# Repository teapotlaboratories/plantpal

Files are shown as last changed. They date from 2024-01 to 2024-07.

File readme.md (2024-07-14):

# Teapotlabs Plantpal
 
 
Meet Teapotlabs Plantpal -  Your pal in plant care! This adorable device uses capacitive sensing to measure soil moisture. Its low-power e-paper display keeps you updated without draining energy. Plus, with the BME688 sensor, it is able to monitor air quality and CO2 levels, ensuring your plants thrive in optimal conditions.

Teapotlabs Plantpal is part of  [Teapotlabs open-hardware project](https://github.com/teapotlaboratories). 

## Sponsorship
Huge thanks to [PCBWay](https://www.pcbway.com) to sponsored this project! All PCB board and PCB Assembly in this project was using their rapid-prototyping services. The process from ordering to delivery of the device was really smooth and easy. We were really happy with the quality of the assembly and especially the customer support that was really easy to work with, where they help us identify and fix issue such as verifying BOM, checking components for assembly and even replacing damaged parts at no cost.

## Acknowledgement
The project won't be possible without the amazing work from people across the globe. The following are the reference to those awesome projects!

 - Soil moisture design from [b-parasite](https://github.com/rbaron/b-parasite) 
 - Solar energy Harvesting from [TSEM](https://hackaday.io/project/159139-tiny-solar-energy-module-tsem)
 - Antenna design from [Picoclick-C3](https://makermoekoe.gitbook.io/picoclick-c3)
 
## Specification

- [ESP32-C6FH4](https://www.espressif.com/sites/default/files/documentation/esp32-c6_datasheet_en.pdf): ESP32-C6 with 4 MB in-package flash
- [AEM10941](https://e-peas.com/product/aem10941): Solar energy harvesting
- USB-C for charging and programming
- ~20uA Deep-Sleep
- 1.54 Inch E-Paper Display
- Sensor:
	- `BME688` for Environmental Sensing
	- Built-in `Soil Moisture` sensor
	- `Battery voltage` sensing
- 500mA charge rate via USB
- 3.7 Volts LiPo Battery

## Revision
- **Revision 1**: Initial public release
- **Revision 2**: Remove via in pad
- **Revision 3**: 
	- Fix incorrect BOM component for D1
	- Fix D6 Polarity
	- Remove Power Gate
	- Change **Soil Sensor** `SENSE_OUT` pin
	- Add EPD power switch
	- Change to 4-layer board
	- Move BME688 to bottom layer
	- Improve antenna layout
- **Revision 4**: Re-wire EPD remaining power to +3V3D
- **Revision 5**: Re-trace Wifi antenna to conform with the new stack-up

## Release
- **Release 4.1**: Based on revision 4.0, with BoM changes.
  - Change charge rate resistor to 2K for 500mA
  - Update solar cell components to latest available  

## Schematics

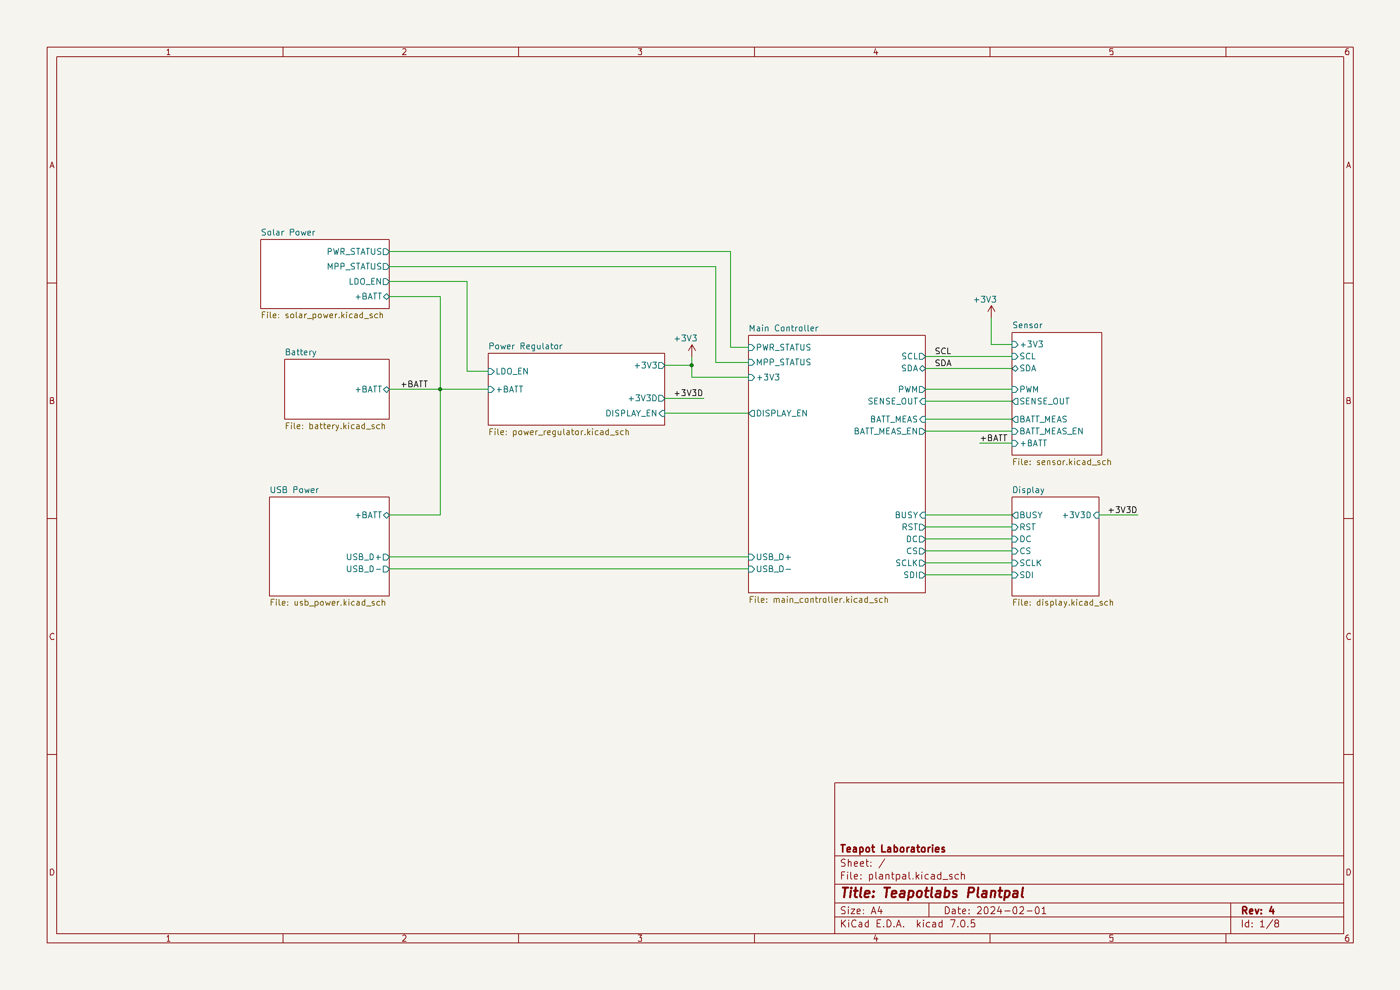
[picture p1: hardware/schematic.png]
schematic


Built using **KiCAD 7.0.5**
A detailed schematic can be found [here](https://raw.githubusercontent.com/teapotlaboratories/plantpal/main/hardware/schematic.pdf)

## Boards
 <p align="center">  pcb_render<br><b>PCB Render</b></p>

Built using KiCAD, the board is design to be as small as possible with all components placed on the top side of the PCB.
> ⚠️ **The following design are based on revision 3 but is similar to revision 4.**

More images can be found [here](https://github.com/teapotlaboratories/plantpal/tree/main/docs/images)

| Top Board | Bottom Board |
|--|--|
| <p align="center"> assembled_front</p> | <p align="center"> assembled_back</p> |
| <p align="center"> pcb_front</p> | <p align="center"> pcb_bottom</p> |

 <p align="center"> pcb<br><b>PCB Top and Bottom Layout</b></p> 

 <p align="center"> pcb<br><b>Assembled Front Close-up</b></p> 
 
### Case and Showcase
<p align="center">  case_render</p>

Built using [TinkerCAD](https://www.tinkercad.com). The case are 3D printable with any generic 3D printer with/without support. The STL files are available [here](https://github.com/teapotlaboratories/plantpal/tree/main/hardware/case)
 <p align="center"><br><b>Case Open</b></p>

`BME688` sensor is available in the back, facing 3 small vents in the back of the case
 <p align="center"><br><b>BME688 Position</b></p>

#### Soil Moisture Sensing Showcase
Based on the amazing project in [b-parasite](https://github.com/rbaron/b-parasite), Plantpal has the built-in soil moisture sensor via capacitive sensing. Using capacitive sensing, enables the device to measure soil moisture without any traces exposed to the environment. See [rbaron's b-parasite](https://github.com/rbaron/b-parasite) project for more information on how the sensor works and more additional information to protect the soil moisture sensor!

<p align="center">soil moisture sensing test<br><b>Soil Moisture Sensing Showcase</b></p>

## Measurement
Power consumption and solar charging current are measured using [Nordic PPK2](https://www.nordicsemi.com/Products/Development-hardware/Power-Profiler-Kit-2)  and [Joulescope](https://joulescope.com).
The following are the summary of the measurement:
- Deep-sleep : **22uA**
- Read Sensor, Update Display, and Store Data to Flash: **31mA @ 2.5s**
- Read Sensor, Update Display, Store Data to Flash, and Publish to MQTT: **54mA @ 3.77s**
- Direct Sunlight Solar Charge: **7.5mA**
  - Note: latest testing shows an average of 10mA
- Indirect Sunlight Solar Charge: **400uA**

> :warning: **Tested on Revision 4-equivalent board, but should be similar to Revision 4** 

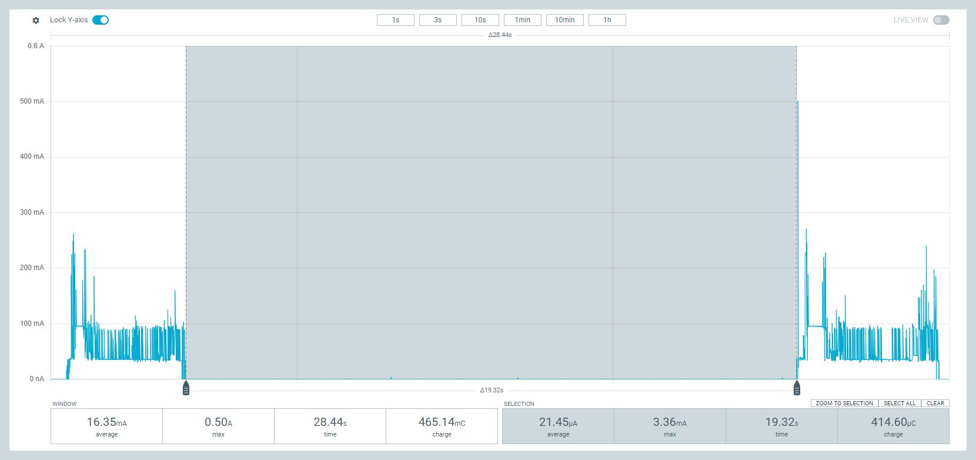
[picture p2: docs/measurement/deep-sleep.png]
deep-sleep
<p align="center"><br><b>Deep-sleep</b></p>

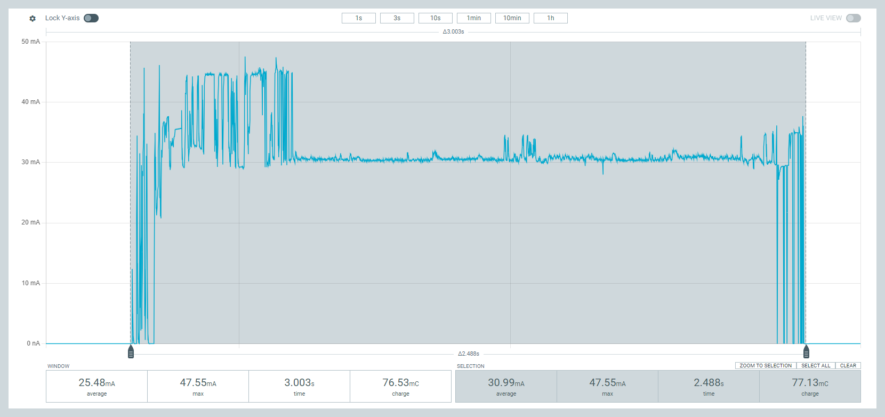
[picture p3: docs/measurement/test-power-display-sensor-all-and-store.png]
power-display-sensor-all-and-store
<p align="center"><br><b>Read Sensor, Update Display, and Store Data to Flash</b></p>

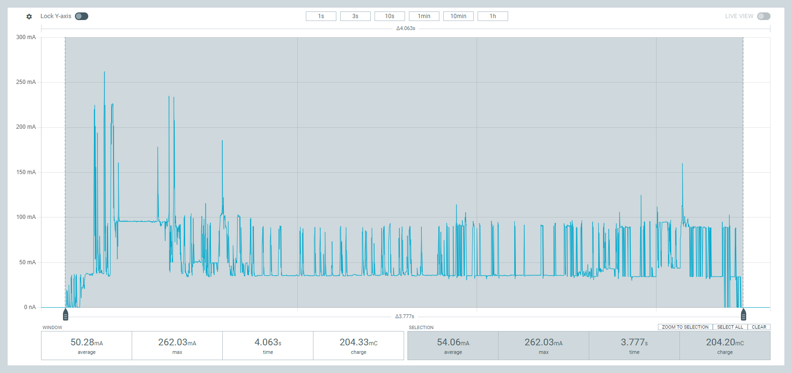
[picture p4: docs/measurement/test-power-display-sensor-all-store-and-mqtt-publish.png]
power-display-sensor-all-store-and-mqtt-publish
<p align="center"><br><b>Read Sensor, Update Display, Store Data to Flash, and Publish to MQTT</b></p>

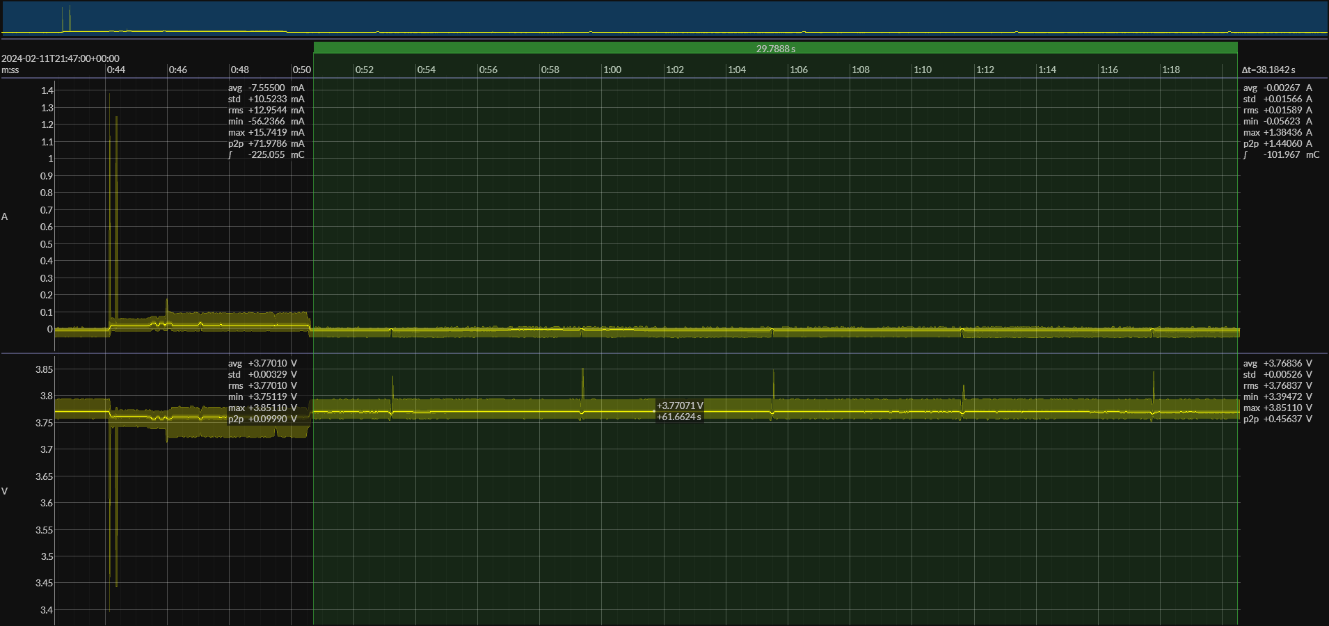
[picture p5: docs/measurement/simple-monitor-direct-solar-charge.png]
simple-monitor-direct-solar-charge
<p align="center"><br><b>Solar Charge - Direct Sunlight</b></p>

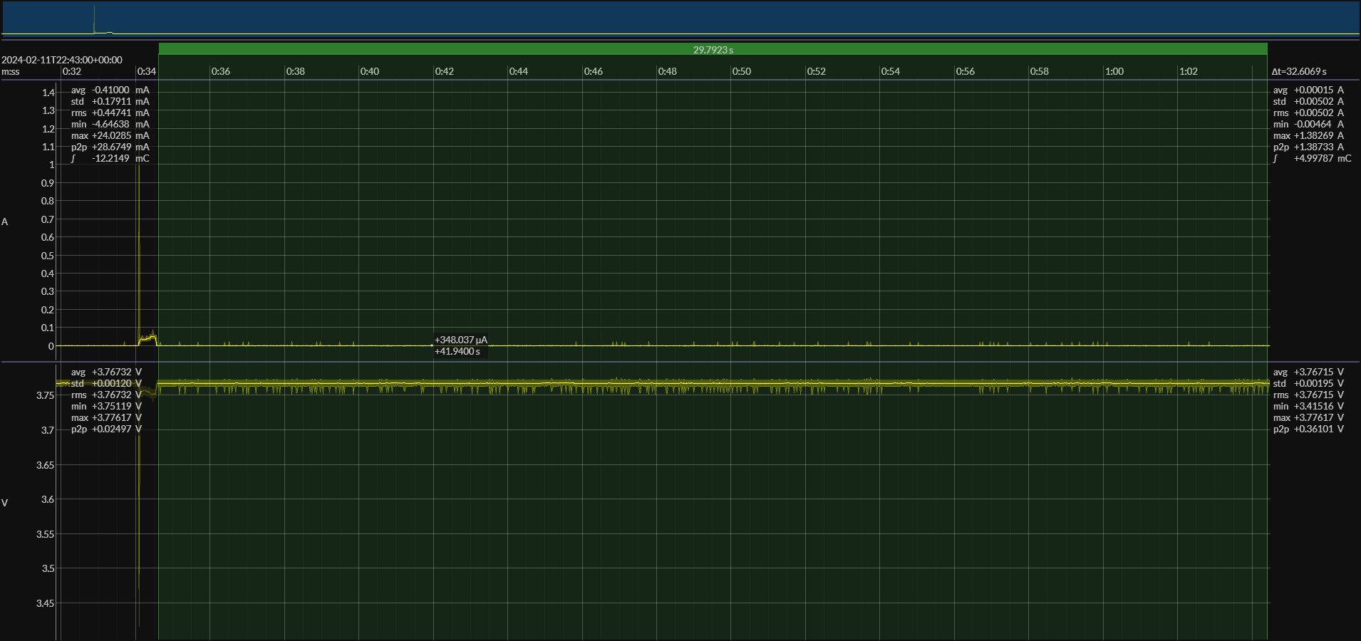
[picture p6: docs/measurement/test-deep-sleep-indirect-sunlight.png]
test-deep-sleep-indirect-sunlight
<p align="center"><br><b>Solar Charge - Indirect Sunlight</b></p>

More measurement can be found [here](https://github.com/teapotlaboratories/plantpal/tree/main/docs/measurement)

## Bill Of Materials
Most of the components are generic and can be bought from any electornics/semi-conductor distributor. The bill of materials can be downloaded [here](https://github.com/teapotlaboratories/plantpal/blob/main/hardware/bill_of_materials.csv).
The EPD display used and tested is `GDEY0154D67` from **GoodDisplay**. The following display should be compatible, but the example code would need to be adjusted:
- GDEW0154T8
- GDEW0154Z17
- GDEW0154Z04
- GDEW0154C39
- GDEW0154I9F

Those displays are available from AliExpress

## Programming
Programming the device can be done easily over the USB-C. 
Out of factory, the ESP32-C6 will be blank and need to be put in `bootloader` mode. The following is a step-by-step guide to initially program the device

  1. Plug-in the USB-C to host computer and check if the device is detected
  2. If not, check that you have the battery plug-in and try to shine the solar cell using any source of bright light ( phone flashlight, sun, lamp )
  3. Wait until the USB is detected in the host computer 
  4. Press and Hold `BOOT` and `RESET` button
  5. Release `RESET` button 
  6. Wait couple seconds
  7. Release `BOOT` button
  8. Plantpal should be in `bootloader` mode and you can flash it via `ESP-IDF` or `Arduino`

<p align="center">plantpal-buttons<br><b>Plantpal buttons</b></p>

A more detailed information about USB behavior on ESP32-C6 can be [here](https://docs.espressif.com/projects/esp-idf/en/latest/esp32c6/api-guides/usb-serial-jtag-console.html)

## How to Purchase
At the moment, we do not mass produce the device. The fastest way you can get the device is to order it directly from the manufacturer [here](https://link.teapotlabs.io/plantpal-order) (does **NOT** include the display and case).
You need to buy the display separately from Aliexpress or other distributor.

If you'd like to buy it from us fully assembled, we might be available and please contact contact@teapotlabs.io

## Disclaimer and notes
Some disclaimer about Plantpal:
- WiFi antenna is not tuned and not certified
- RTC components have not been tested
- The solar charge rate is 1.5mA lower than [Teapotlabs BWLR1E](https://github.com/teapotlaboratories/bwlr1e) even though they use the same components and configuration.
  - Note: latest testing shows an average of 10mA

## Questions?
For any questions feel free to create a issue or contact contact@teapotlabs.io

## License
The product is open-source! However, some part of library used under **firmware** or **hardware**, might have it's own license.
Please reach out or create a ticket if **Teapotlabs Plantpal** violated any licenses.



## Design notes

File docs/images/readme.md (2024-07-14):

# Images for Documentation

## Assembled Back
<p align="center">assembled_back</p>

## Assembled Back Close-up
<p align="center">assembled_back_close_up</p>

## Assembled Front
<p align="center">assembled_front</p>

## Assembled Front Close-up
<p align="center">assembled_front_close_up</p>

## Case Close
<p align="center">case_close</p>

## Case Close Back
<p align="center">case_close</p>

## Case Open
<p align="center">case_open</p>

## Case Render
<p align="center">case_render</p>

## Device
<p align="center">device</p>

## Device Button
<p align="center">device</p>

## PCB Bottom
<p align="center">pcb_bottom</p>

## PCB Render
<p align="center">pcb_render</p>

## PCB Top
<p align="center">pcb_top</p>

## Soil Moisture Showcase
<p align="center">soil_moisture_showcase</p>

## With AA for Comparison
<p align="center">with_aa_for_comparison</p>

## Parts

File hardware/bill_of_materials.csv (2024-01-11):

Id | Designator | Quantity | Manufacturer | Manufacturer Part Number | Value | Part Description | Footprint | Type | Distributor | Distributor Part Number | Distributor Link | Datasheet
1 | AE1 | 1 | Walsin Technology Corporation | RFECA3216060A1T | RFECA3216060A1T | Chip RF Antenna 2.4GHz 2dBi | RFECA3216060A1T | SMD | Digikey | 1292-1035-1-ND | https://www.digikey.com/en/products/detail/walsin-technology-corporation/RFECA3216060A1T/3877063 | http://www.passivecomponent.com/wp-content/uploads/2018/10/ASC_RFECA3216060A1T_V09.pdf
2 | BT1 | 1 | JST Sales America | S2B-PH-SM4-TB(LF)(SN) | S2B-PH-SM4-TB(LF)(SN) | Wire To Board Connector 1x2P PH 2mm Male 2A P=2mm | JST_PH_S2B-PH-SM4-TB_1x02-1MP_P2.00mm_Horizontal | SMD | LCSC | C295747 | https://www.lcsc.com/product-detail/Wire-To-Board-Wire-To-Wire-Connector_JST-Sales-America-S2B-PH-SM4-TB-LF-SN_C295747.html | https://datasheet.lcsc.com/lcsc/2102031704_JST-Sales-America-S2B-PH-SM4-TB-LF-SN_C295747.pdf
3 | C1, C2 | 2 | Murata Electronics | GCM1555C1H120FA16D | 12p | Ceramic Capacitors 50V 12pF C0G ±1% | 0402_1005Metric | SMD | LCSC | C393682 | https://www.lcsc.com/product-detail/Multilayer-Ceramic-Capacitors-MLCC-SMD-SMT_Murata-Electronics-GCM1555C1H120FA16D_C393682.html | https://datasheet.lcsc.com/lcsc/2304140030_Murata-Electronics-GCM1555C1H120FA16D_C393682.pdf
4 | C3, C4 | 2 | Murata Electronics | GRM1555C1H100FA01D | 10p | Ceramic Capacitors 50V 10pF C0G ±1% | 0402_1005Metric | SMD | LCSC | C161520 | https://www.lcsc.com/product-detail/Multilayer-Ceramic-Capacitors-MLCC-SMD-SMT_Murata-Electronics-GRM1555C1H100FA01D_C161520.html | https://datasheet.lcsc.com/lcsc/1811081522_Murata-Electronics-GRM1555C1H100FA01D_C161520.pdf
5 | C5, C19, C20, C23, C24, C25, C26 | 7 | Samsung Electro-Mechanics | CL10A106KP8NNNC | 10u | Ceramic Capacitor 10V 10uF X5R ±10% 0603 | 0603_1608Metric | SMD | LCSC | C19702 | https://www.lcsc.com/product-detail/Multilayer-Ceramic-Capacitors-MLCC-SMD-SMT_Samsung-Electro-Mechanics-CL10A106KP8NNNC_C19702.html | https://datasheet.lcsc.com/lcsc/2304140030_Samsung-Electro-Mechanics-CL10A106KP8NNNC_C19702.pdf
6 | C6, C7, C10, C11, C13, C27, C28, C29 | 8 | Samsung Electro-Mechanics | CL05B104KO5NNNC | 100n | Ceramic Capacitor 16V 100nF X7R ±10% | 0402_1005Metric | SMD | LCSC | C1525 | https://www.lcsc.com/product-detail/Multilayer-Ceramic-Capacitors-MLCC-SMD-SMT_Samsung-Electro-Mechanics-CL05B104KO5NNNC_C1525.html | https://datasheet.lcsc.com/lcsc/2304140030_Samsung-Electro-Mechanics-CL05B104KO5NNNC_C1525.pdf
7 | C8 | 1 | YAGEO | CC0402KRX7R7BB103 | 10n | Ceramic Capacitors 16V 10nF X7R ±10% | 0402_1005Metric | SMD | LCSC | C327009 | https://www.lcsc.com/product-detail/Multilayer-Ceramic-Capacitors-MLCC-SMD-SMT_YAGEO-CC0402KRX7R7BB103_C327009.html | https://datasheet.lcsc.com/lcsc/1811141241_YAGEO-CC0402KRX7R7BB103_C327009.pdf
8 | C9, C14, C31, C32, C33, C34, C35, C36, C37, C38, C39 | 11 | Murata Electronics | GRM155Z71A105KE01D | 1u | Ceramic Capacitors 10V 1uF X7R ±10% | 0402_1005Metric | SMD | LCSC | C528974 | https://www.lcsc.com/product-detail/Multilayer-Ceramic-Capacitors-MLCC-SMD-SMT_Murata-Electronics-GRM155Z71A105KE01D_C528974.html | https://datasheet.lcsc.com/lcsc/2005261833_Murata-Electronics-GRM155Z71A105KE01D_C528974.pdf
9 | C17 | 1 | YAGEO | CC0402KRX7R7BB103 | 10n | Ceramic Capacitors 16V 10nF X7R ±10% | 0402_1005Metric | SMD | LCSC | C327009 | https://www.lcsc.com/product-detail/Multilayer-Ceramic-Capacitors-MLCC-SMD-SMT_YAGEO-CC0402KRX7R7BB103_C327009.html | https://datasheet.lcsc.com/lcsc/1811141241_YAGEO-CC0402KRX7R7BB103_C327009.pdf
10 | C18 | 1 | Samsung Electro-Mechanics | CL05B104KO5NNNC | 100n | Ceramic Capacitor 16V 100nF X7R ±10% | 0402_1005Metric | SMD | LCSC | C1525 | https://www.lcsc.com/product-detail/Multilayer-Ceramic-Capacitors-MLCC-SMD-SMT_Samsung-Electro-Mechanics-CL05B104KO5NNNC_C1525.html | https://datasheet.lcsc.com/lcsc/2304140030_Samsung-Electro-Mechanics-CL05B104KO5NNNC_C1525.pdf
11 | C21, C22 | 2 | Murata Electronics | GRM188R61A226ME15D | 22u | Ceramic Capacitors 10V 22uF X5R ±20% | 0603_1608Metric | SMD | LCSC | C84419 | https://www.lcsc.com/product-detail/Multilayer-Ceramic-Capacitors-MLCC-SMD-SMT_Murata-Electronics-GRM188R61A226ME15D_C84419.html | https://www.mouser.com/datasheet/2/281/1/GRM188R61A226ME15_02A-1985787.pdf
12 | C30 | 1 | Samsung Electro-Mechanics | CL05B102KB5NNNC | 1n | Ceramic Capacitors 50V 1nF X7R ±10% | 0402_1005Metric | SMD | LCSC | C14442 | https://www.lcsc.com/product-detail/Multilayer-Ceramic-Capacitors-MLCC-SMD-SMT_Samsung-Electro-Mechanics-CL05B102KB5NNNC_C14442.html | https://datasheet.lcsc.com/lcsc/2304140030_Samsung-Electro-Mechanics-CL05B102KB5NNNC_C14442.pdf
13 | C40, C41 | 2 | Samsung Electro-Mechanics | CL10A475KA8NQNC | 4u7 | Ceramic Capacitors 25V 4.7uF X5R ±10% | 0603_1608Metric | SMD | LCSC | C69335 | https://www.lcsc.com/product-detail/Multilayer-Ceramic-Capacitors-MLCC-SMD-SMT_Samsung-Electro-Mechanics-CL10A475KA8NQNC_C69335.html | https://datasheet.lcsc.com/lcsc/1810261513_Samsung-Electro-Mechanics-CL10A475KA8NQNC_C69335.pdf
14 | D1 | 1 | Vishay Intertech | VLMO1300-GS08 | VLMO1300-GS08 | Orange 2V 20mA | 0603_1608Metric | SMD | LCSC | C5184984 | https://www.lcsc.com/product-detail/Light-Emitting-Diodes-LED_Vishay-Intertech-VLMO1300-GS08_C5184984.html | https://datasheet.lcsc.com/lcsc/2209291030_Vishay-Intertech-VLMO1300-GS08_C5184984.pdf
15 | D3 | 1 | ST(Semtech) | LL4148 | LL4148 | Switching Diode 75V 500mW 1V@10mA 4ns 0.2A | MiniMELF | SMD | LCSC | C9808 | https://www.lcsc.com/product-detail/Switching-Diode_ST-Semtech-LL4148_C9808.html | https://datasheet.lcsc.com/lcsc/2304140030_ST-Semtech-LL4148_C9808.pdf
16 | D4, D5, D6 | 3 | onsemi | MBR0530T1G | MBR0530 | Schottky Barrier Diodes 30V 430mV@500mA 500mA | SOD-123 | SMD | LCSC | C82046 | https://www.lcsc.com/product-detail/Schottky-Barrier-Diodes-SBD_onsemi-MBR0530T1G_C82046.html | http://www.mccsemi.com/up_pdf/MBR0520~MBR0580(SOD123).pdf
17 | F1 | 1 | RUILON(Shenzhen Ruilongyuan Elec) | SMD0805P075TF | 0.75A | Resettable Fuses 6V 750mA 40A 1.5A | 0805_2012Metric | SMD | LCSC | C20979 | https://www.lcsc.com/product-detail/Resettable-Fuses_RUILON-Shenzhen-Ruilongyuan-Elec-SMD0805P075TF_C20979.html | https://datasheet.lcsc.com/lcsc/2304140030_RUILON-Shenzhen-Ruilongyuan-Elec-SMD0805P075TF_C20979.pdf
18 | FB1 | 1 | TDK | MMZ1608B601CTAH0 | MMZ1608B601CTAH0 | Ferrite Beads 400mΩ ±25% 600Ω@100MHz | 0603_1608Metric | SMD | LCSC | C97120 | https://www.lcsc.com/product-detail/Ferrite-Beads_TDK-MMZ1608B601CTAH0_C97120.html | https://datasheet.lcsc.com/lcsc/2304140030_TDK-MMZ1608B601CTAH0_C97120.pdf
19 | J1 | 1 | XKB Connectivity | U262-161N-4BVC11 | U262-161N-4BVC11 | USB Connectors Type-C 3A USB 3.1 16P | XKB_U262-16XN-4BVC11 | SMD | LCSC | C319148 | https://www.lcsc.com/product-detail/USB-Connectors_XKB-Connectivity-U262-161N-4BVC11_C319148.html | https://datasheet.lcsc.com/lcsc/2110151630_XKB-Connectivity-U262-161N-4BVC11_C319148.pdf
20 | J4 | 1 | HCTL | HC-FPC-05-09-24RLTAG | HC-FPC-05-09-24RLTAG | FFC & FPC Connectors Clamshell 24P Bottom Contact P=0.5mm | FPC-SMD_24P-P0.50_HC-FPC-05-09-24RLTAG | SMD | LCSC | C5213757 | https://www.lcsc.com/product-detail/FFC-FPC-Connectors_HCTL-HC-FPC-05-09-24RLTAG_C5213757.html | https://datasheet.lcsc.com/lcsc/2210261730_HCTL-HC-FPC-05-09-24RLTAG_C5213757.pdf
21 | L1 | 1 | Murata Electronics | LQW15AN2N2G80D | 2n2 | Power Inductors 2.53A 2.2nH ±2% | 0402_1005Metric | SMD | LCSC | C412264 | https://www.lcsc.com/product-detail/Power-Inductors_Murata-Electronics-LQW15AN2N2G80D_C412264.html | https://datasheet.lcsc.com/lcsc/2304140030_Murata-Electronics-LQW15AN2N2G80D_C412264.pdf
22 | L2 | 1 | UNI-ROYAL(Uniroyal Elec) | 0402WGF0000TCE | 0 | Resistor 62.5mW ±1% 0Ω | 0402_1005Metric | SMD | LCSC | C17168 | https://www.lcsc.com/product-detail/Chip-Resistor-Surface-Mount_UNI-ROYAL-Uniroyal-Elec-0402WGF0000TCE_C17168.html | https://datasheet.lcsc.com/lcsc/2206010216_UNI-ROYAL-Uniroyal-Elec-0402WGF0000TCE_C17168.pdf
23 | L3 | 1 | Coilcraft | LPS4012-103MRC | 10u 0.55A | Power Inductors - SMD 10uH Shld 20% 1.1A 350 mOhms | LPS4012-103MRB | SMD | Mouser | 994-LPS4012-103MRC | https://www.mouser.com/ProductDetail/Coilcraft/LPS4012-103MRC?qs=QQJxVsr8EGanxcNaj8pdMQ%3D%3D | https://www.mouser.com/datasheet/2/597/lps4012-1890589.pdf
24 | L4 | 1 | TDK | MLZ1608M100WT000 | 10u | Power Inductors 10uH ±20% 90mA 1.05Ω | 0603_1608Metric | SMD | LCSC | C76798 | https://www.lcsc.com/product-detail/Inductors-SMD_TDK-MLZ1608M100WT000_C76798.html | https://product.tdk.com/system/files/dam/doc/product/inductor/inductor/smd/catalog/inductor_commercial_decoupling_mlz1608_en.pdf
25 | L5 | 1 | cjiang (Changjiang Microelectronics Tech) | FNR4012S100MT | 10u 1A | Power Inductors 1A 10uH ±20% 1.1A SMD,4x4mm | FNR4012S | SMD | LCSC | C167785 | https://www.lcsc.com/product-detail/Power-Inductors_cjiang-Changjiang-Microelectronics-Tech-FNR4012S100MT_C167785.html | https://datasheet.lcsc.com/lcsc/2304140030_cjiang--Changjiang-Microelectronics-Tech-FNR4012S100MT_C167785.pdf
26 | Q1, Q2, Q5, Q9 | 4 | Diodes Incorporated | DMG1012UW-7 | DMG1012UW | MOSFET N Channel 20V 1A 450mΩ@4.5V,600mA 290mW | SOT-323_SC-70 | SMD | LCSC | C156390 | https://www.lcsc.com/product-detail/MOSFETs_Diodes-Incorporated-DMG1012UW-7_C156390.html | https://datasheet.lcsc.com/lcsc/1806090918_Diodes-Incorporated-DMG1012UW-7_C156390.pdf
27 | Q3 | 1 | Jiangsu Changjing Electronics Technology Co., Ltd. | MMBT3906 2A | MMBT3906 | Bipolar Transistors 40V 200mW 100@10mA,1V 200mA PNP | SOT-23 | SMD | LCSC | C2143 | https://www.lcsc.com/product-detail/Bipolar-Transistors-BJT_Jiangsu-Changjing-Electronics-Technology-Co-Ltd-MMBT3906-2A_C2143.html | https://datasheet.lcsc.com/lcsc/1809211015_Jiangsu-Changjing-Electronics-Technology-Co---Ltd--MMBT3906-2A_C2143.pdf
28 | Q4, Q8 | 2 | TECH PUBLIC | PMV32UP | PMV32UP | MOSFET P Channel 20V 4A 52mΩ@4.5V | SOT-23 | SMD | LCSC | C2959851 | https://www.lcsc.com/product-detail/MOSFETs_TECH-PUBLIC-PMV32UP_C2959851.html | https://datasheet.lcsc.com/lcsc/2201211500_TECH-PUBLIC-PMV32UP_C2959851.pdf
29 | Q6 | 1 | Alpha & Omega Semicon | AO3407A | AO3407A | MOSFET P Channel 30V 4.3A 48mΩ@10V,4.3A 1.4W | SOT-23 | SMD | LCSC | C15155 | https://www.lcsc.com/product-detail/MOSFETs_Alpha-Omega-Semicon-AO3407A_C15155.html | https://datasheet.lcsc.com/lcsc/1810231523_Alpha---Omega-Semicon-AO3407A_C15155.pdf
30 | Q7 | 1 | Vishay Intertech | SI1308EDL-T1-GE3 | SI1308EDL | MOSFET N Channel 30V 1.4A 132mΩ@10V,1.4A | SOT-323_SC-70 | SMD | LCSC | C469327 | https://www.lcsc.com/product-detail/MOSFETs_Vishay-Intertech-SI1308EDL-T1-GE3_C469327.html | https://datasheet.lcsc.com/lcsc/1912202016_Vishay-Intertech-SI1308EDL-T1-GE3_C469327.pdf
31 | R1, R2 | 2 | UNI-ROYAL(Uniroyal Elec) | 0402WGF220JTCE | 22 | Resistor 62.5mW ±1% 22Ω | R_0402_1005Metric | SMD | LCSC | C25092 | https://www.lcsc.com/product-detail/Chip-span-style-background-color-ff0-Resistor-span-Surface-Mount_UNI-ROYAL-Uniroyal-Elec-0402WGF220JTCE_C25092.html | https://datasheet.lcsc.com/lcsc/2205311900_UNI-ROYAL-Uniroyal-Elec-0402WGF220JTCE_C25092.pdf
32 | R3, R4, R5, R6, R9, R16, R17, R18, R19, R21 | 10 | UNI-ROYAL(Uniroyal Elec) | 0402WGF1002TCE | 10K | Resistors 62.5mW ±1% 10kΩ | R_0402_1005Metric | SMD | LCSC | C25744 | https://www.lcsc.com/product-detail/Chip-Resistor-Surface-Mount_UNI-ROYAL-Uniroyal-Elec-0402WGF1002TCE_C25744.html | https://datasheet.lcsc.com/lcsc/2206010100_UNI-ROYAL-Uniroyal-Elec-0402WGF1002TCE_C25744.pdf
33 | R7, R14, R22, R23, R24, R26, R28, R29 | 8 | UNI-ROYAL(Uniroyal Elec) | 0402WGF1004TCE | 1M | Resistor 62.5mW ±1% 1MΩ | R_0402_1005Metric | SMD | LCSC | C26083 | https://www.lcsc.com/product-detail/Chip-Resistor-Surface-Mount_UNI-ROYAL-Uniroyal-Elec-0402WGF1004TCE_C26083.html | https://datasheet.lcsc.com/lcsc/2206010030_UNI-ROYAL-Uniroyal-Elec-0402WGF1004TCE_C26083.pdf
34 | R8, R10, R11 | 3 | UNI-ROYAL(Uniroyal Elec) | 0402WGF5101TCE | 5K1 | Resistor 62.5mW ±1% 5.1kΩ | R_0402_1005Metric | SMD | LCSC | C25905 | https://www.lcsc.com/product-detail/Chip-Resistor-Surface-Mount_UNI-ROYAL-Uniroyal-Elec-0402WGF5101TCE_C25905.html | https://datasheet.lcsc.com/lcsc/2206010045_UNI-ROYAL-Uniroyal-Elec-0402WGF5101TCE_C25905.pdf
35 | R12, R13 | 2 | UNI-ROYAL(Uniroyal Elec) | 0402WGF1001TCE | 1K | Resistor 62.5mW ±1% 1kΩ | R_0402_1005Metric | SMD | LCSC | C11702 | https://www.lcsc.com/product-detail/Chip-Resistor-Surface-Mount_UNI-ROYAL-Uniroyal-Elec-0402WGF1001TCE_C11702.html | https://datasheet.lcsc.com/lcsc/2206010216_UNI-ROYAL-Uniroyal-Elec-0402WGF1001TCE_C11702.pdf
36 | R20 | 1 | UNI-ROYAL(Uniroyal Elec) | 0402WGF4701TCE | 4K7 | Resistor 62.5mW ±1% 4.7kΩ | R_0402_1005Metric | SMD | LCSC | C25900 | https://www.lcsc.com/product-detail/Chip-Resistor-Surface-Mount_UNI-ROYAL-Uniroyal-Elec-0402WGF4701TCE_C25900.html | https://datasheet.lcsc.com/lcsc/2206010045_UNI-ROYAL-Uniroyal-Elec-0402WGF4701TCE_C25900.pdf
37 | R25 | 1 | Vishay Intertech | RCWE0402R470FKEA | 470m | Resistor 125mW ±1% 470mΩ | R_0402_1005Metric | SMD | LCSC | C962578 | https://www.lcsc.com/product-detail/Chip-Resistor-Surface-Mount_Vishay-Intertech-RCWE0402R470FKEA_C962578.html | https://datasheet.lcsc.com/lcsc/2305172030_Vishay-Intertech-RCWE0402R470FKEA_C962578.pdf
38 | SC1, SC2, SC3, SC4 | 4 | ANYSOLAR Ltd | KXOB25-05X3TF-TR | KXOB25-05X3TF-TR | Solar Cell G3 Thin 2.07V 30.9MW | KXOB25-05X3F | SMD | Digikey | 2994-KXOB25-05X3TF-TRCT-ND | https://www.digikey.com/en/products/detail/anysolar-ltd/KXOB25-05X3TF-TR/13999164 | https://waf-e.dubudisk.com/anysolar.dubuplus.com/techsupport@anysolar.biz/O18Atf9/DubuDisk/www/Gen3/KXOB25-05X3TF%20DATA%20SHEET%20202012.pdf
39 | SW1, SW2 | 2 | Omron Electronics | B3U-3000P | B3U-3000P | Tactile Switches NO 50mA 100MΩ 12V 1.59N | B3U-3000P | SMD | LCSC | C963349 | https://www.lcsc.com/product-detail/Tactile-Switches_Omron-Electronics-B3U-3000P_C963349.html | https://datasheet.lcsc.com/lcsc/2012042009_Omron-Electronics-B3U-3000P_C963349.pdf
40 | U1 | 1 | Espressif Systems | ESP32-C6FH4 | ESP32-C6FH4 | Wireless SOC Bluetooth, WiFi Bluetooth v5.0, Thread, Zigbee® 2.4 | QFN-32-1EP_5x5mm_P0.5mm_EP3.6x3.6mm | SMD | Digikey | 1904-ESP32-C6FH4CT-ND | https://www.digikey.com/en/products/detail/espressif-systems/ESP32-C6FH4/18587545 | https://www.espressif.com/sites/default/files/documentation/esp32-c6_datasheet_en.pdf
41 | U2 | 1 | STMicroelectronics | USBLC6-2P6 | USBLC6-2P6 | ESD Protection 6V 17V 2 Unidirectional 5.25V | SOT-666 | SMD | LCSC | C15999 | https://www.lcsc.com/product-detail/ESD-Protection-Devices_STMicroelectronics-USBLC6-2P6_C15999.html | https://www.st.com/resource/en/datasheet/usblc6-2.pdf
42 | U3 | 1 | Microchip Tech | MCP73831T-2ACI/OT | MCP73831T-2ACI/OT | Battery Management IC 6V LiPoly 1500mA | SOT-23-5 | SMD | LCSC | C424093 | https://www.lcsc.com/product-detail/Battery-Management-ICs_Microchip-Tech-MCP73831T-2ACI-OT_C424093.html | http://ww1.microchip.com/downloads/en/DeviceDoc/20001984g.pdf
43 | U4 | 1 | e-peas | AEM10941-QFN | AEM10941 | PMIC IC - Photovoltaic Energy Harvesting Manager | QFN-28-1EP_5x5mm_P0.5mm_EP3.35x3.35mm | SMD | Mouser | 120-AEM10941-QFN | https://www.mouser.com/ProductDetail/e-peas/AEM10941-QFN?qs=W%2FMpXkg%252BdQ7CeqB2lBPbRQ%3D%3D | https://e-peas.com/wp-content/uploads/2023/07/e-peas-AEM10941-datasheet-solar-energy-harvesting.pdf
44 | U6 | 1 | Torex Semiconductor | XC6220B331MR-G | XC6220 | LDO Voltage Regulators 1A | SOT-23-5 | SMD | LCSC | C86534 | https://www.lcsc.com/product-detail/Linear-Voltage-Regulators-LDO_Torex-Semicon-XC6220B331MR-G_C86534.html | https://www.mouser.com/datasheet/2/760/TOSL_S_A0009829727_1-2575077.pdf
45 | U7 | 1 | Bosch Sensortec | BME688 | BME688 | Gas, Humidity, Pressure, Temperature Sensor I²C, SPI Output | Bosch_LGA-8_3x3mm_P0.8mm_ClockwisePinNumbering | SMD | Digikey | 828-BME688CT-ND | https://www.digikey.com/en/products/detail/bosch-sensortec/BME688/13681261 | https://www.bosch-sensortec.com/media/boschsensortec/downloads/datasheets/bst-bme688-ds000.pdf
46 | Y1 | 1 | CITIZEN | CM315D32768DZFT | CM315D32768DZFT | Crystals 32.768kHz 12.5pF ±20ppm | Crystal_SMD_3215-2Pin_3.2x1.5mm | SMD | LCSC | C182057 | https://www.lcsc.com/product-detail/Crystals_CITIZEN-CM315D32768DZFT_C182057.html | https://datasheet.lcsc.com/lcsc/1810161213_CITIZEN-CM315D32768DZFT_C182057.pdf
47 | Y2 | 1 | TROQ | R940000171 | R940000171 | Crystals 40MHz 9pF ±10ppm | Crystal_SMD_2016-4Pin_2.0x1.6mm | SMD | LCSC | C2929402 | https://www.lcsc.com/product-detail/Crystals_TROQ-R940000171_C2929402.html | https://datasheet.lcsc.com/lcsc/2201121400_TROQ-R940000171_C2929402.pdf
48 | C12, C15, C16 | 3 | - | - | DNP | - | 0402_1005Metric | - | - | - | - | -

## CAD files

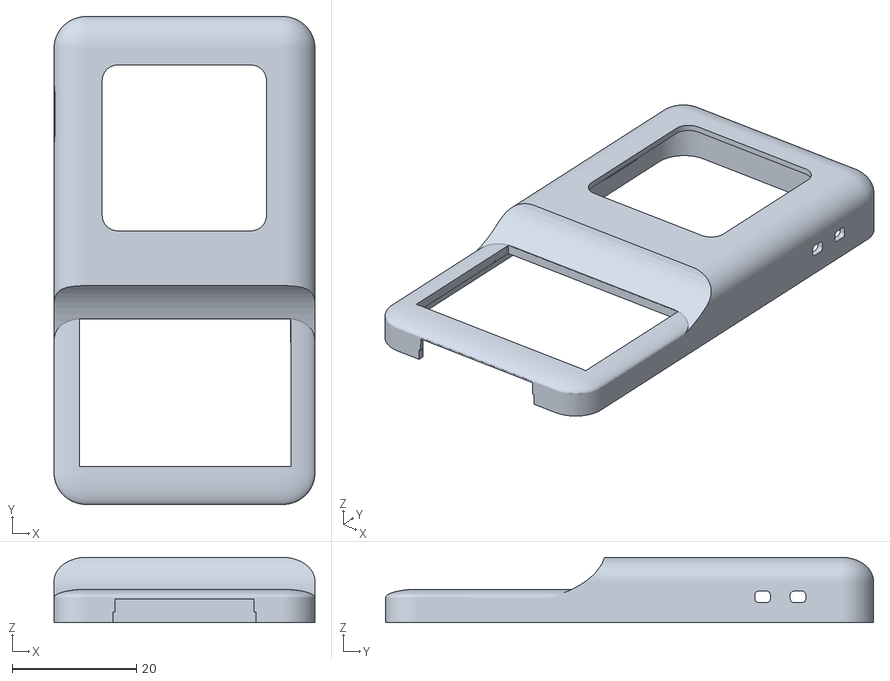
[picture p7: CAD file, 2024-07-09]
hardware/case/resin/top.stl
42.0 x 78.5 x 10.5

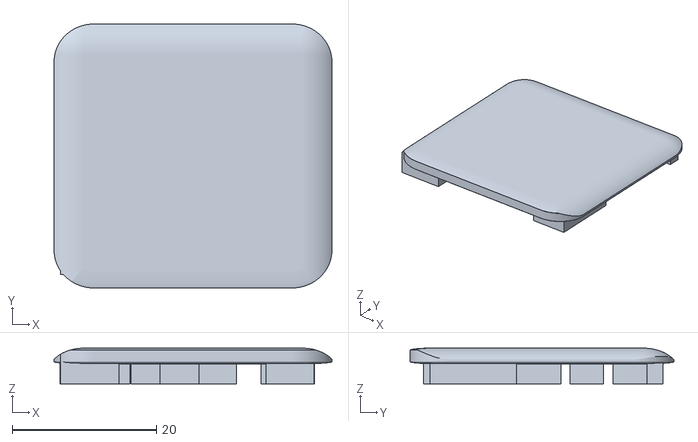
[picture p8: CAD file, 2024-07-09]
hardware/case/resin/display_support.stl
38.6 x 36.6 x 4.96

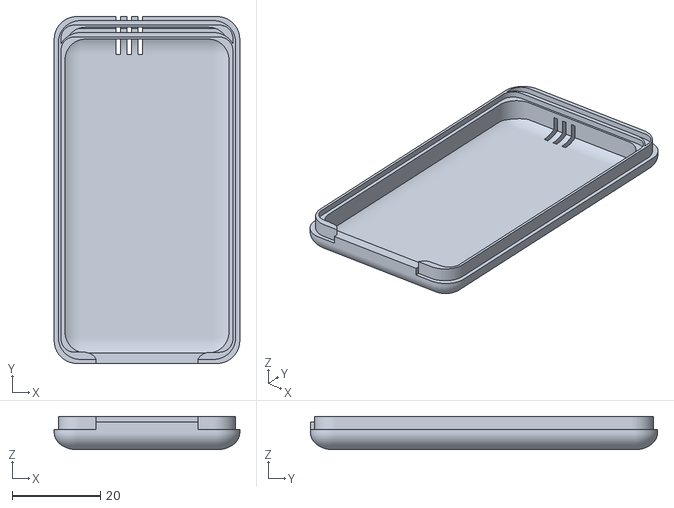
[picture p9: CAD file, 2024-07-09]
hardware/case/resin/bottom.stl
42.0 x 78.5 x 7.56

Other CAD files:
hardware/case/top.stl
hardware/case/bottom.stl
hardware/case/display_support.stl

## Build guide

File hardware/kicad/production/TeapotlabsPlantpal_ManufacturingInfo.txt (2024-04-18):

Thickness = 1.6mm

--------------------

Size: 38.4 x 128.5mm
Number of layers: 4
Material: TG150-160 FR-4

Min. track/spacing: 5/5mil
Min. hole size: 0.3mm

Solder mask: Red
Silkscreen: White

--------------------

SUGGESTED STACK-UP

L1	Copper		1oz					plantpal-F_Cu.gbr

	Prepreg		0.137mm		Dk=4.29 (2116)

L2	Copper		1oz					plantpal-In1_Cu.gbr

	Core		Core 1.2mm

L3	Copper		1oz					plantpal-In2_Cu.gbr

	Prepreg		0.137mm			Dk=4.29 (2116)

L4	Copper		1oz					plantpal-B_Cu.gbr

--------------------

SENSITIVE COMPONENTS

Solar cell: SC1, SC2, SC3, SC4
- recommends 220°C peak temperatures at the reflow zone above 175°C for about 50 seconds
- or manual soldering is recommended under 260°C for 2 sec.

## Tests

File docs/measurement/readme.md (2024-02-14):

# Measurement
Power consumption and solar charging current are measured using [Nordic PPK2](https://www.nordicsemi.com/Products/Development-hardware/Power-Profiler-Kit-2)  and [Joulescope](https://joulescope.com).
The following are the summary of the measurement:
- Deep-sleep : **22uA**
- Read Sensor, Update Display, and Store Data to Flash: **31mA @ 2.5s**
- Read Sensor, Update Display, Store Data to Flash, and Publish to MQTT: **54mA @ 3.77s**
- Direct Sunlight Solar Charge: **7.5mA**
- Indirect Sunlight Solar Charge: **400uA**

## Deep-sleep
<p align="center">deep-sleep</p>

## Solar Charge - Direct
<p align="center">simple-monitor-direct-solar-charge</p>

## Solar Charge - Indirect
<p align="center">test-deep-sleep-indirect-sunlight</p>

## Display Full Refresh
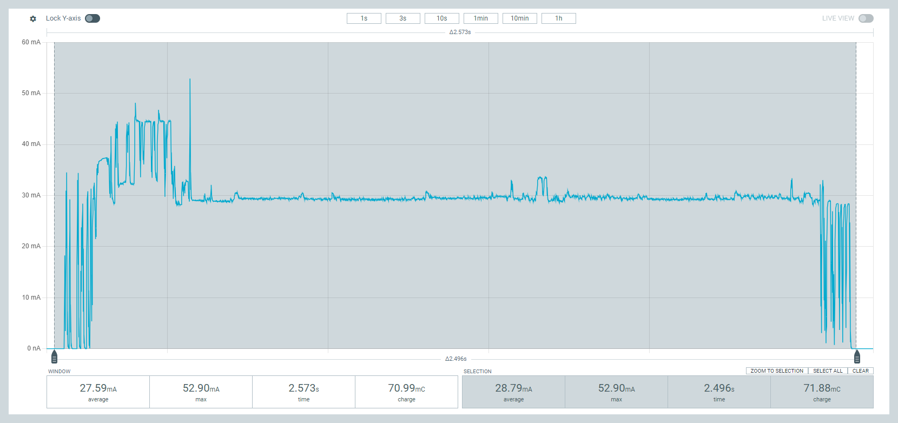
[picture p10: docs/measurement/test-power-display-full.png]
test-power-display-full


## Read Sensor, Update Display, and Store Data to Flash
<p align="center">test-power-display-sensor-all-and-store</p>

##  Read Sensor, Update Display, Store Data to Flash, and Publish to MQTT
<p align="center">test-power-display-sensor-all-store-and-mqtt-publish</p>

## Read All Sensor
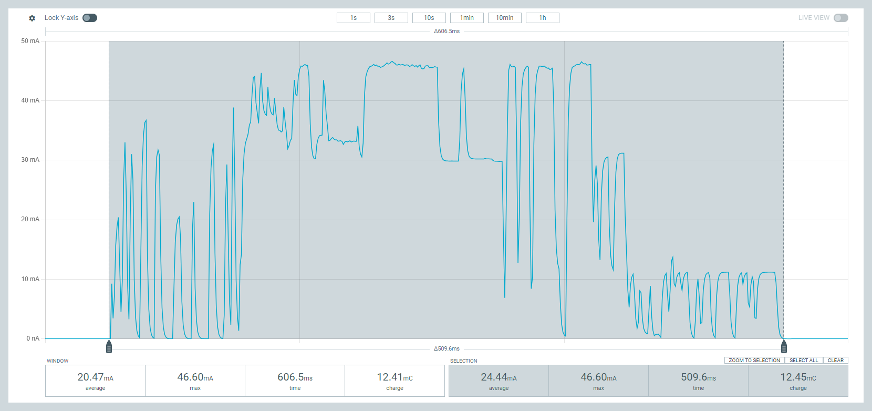
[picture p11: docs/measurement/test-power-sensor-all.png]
test-power-sensor-all


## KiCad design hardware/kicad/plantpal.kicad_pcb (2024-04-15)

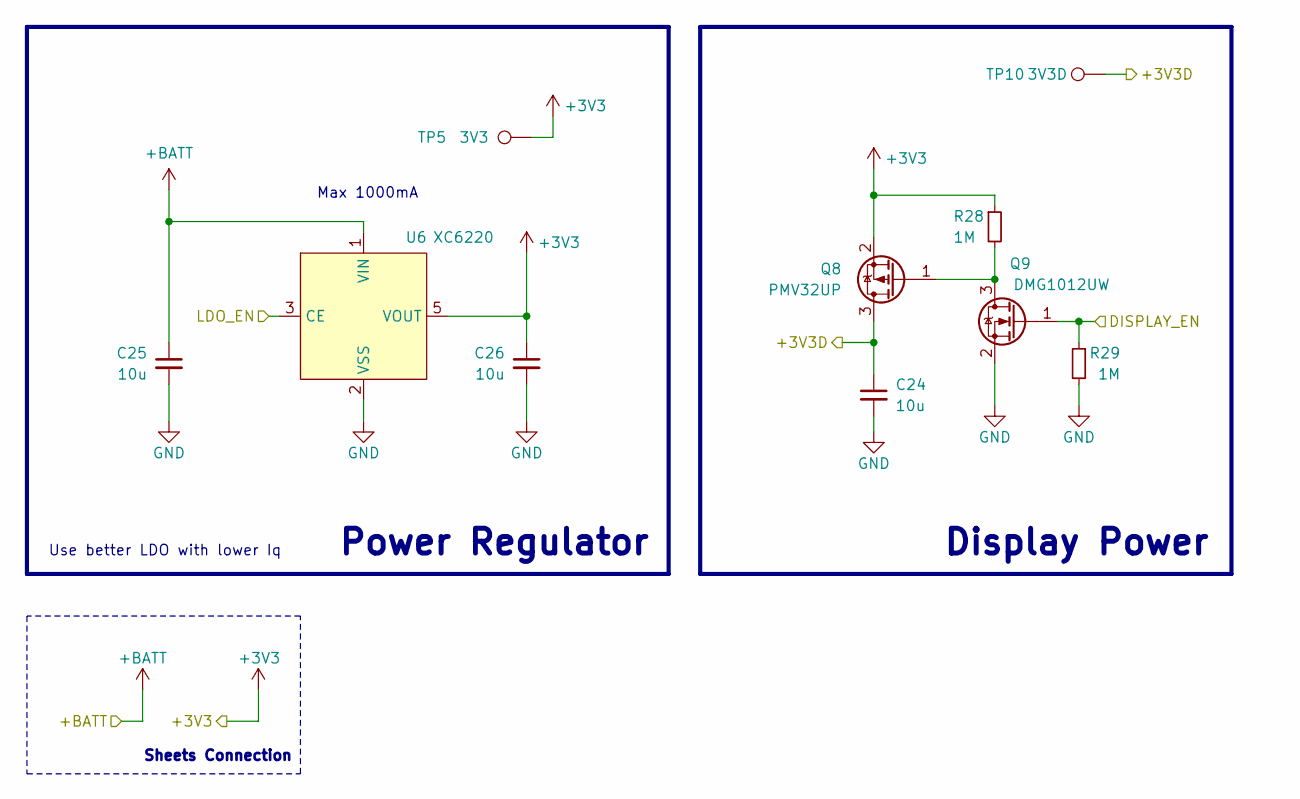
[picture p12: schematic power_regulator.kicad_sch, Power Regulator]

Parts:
C24, C25, C26: 10u; C_0603_1608Metric; Part Description Ceramic Capacitor 10V 10uF X5R ±10% 0603
Q8: PMV32UP; SOT-23; Part Description MOSFET P Channel 20V 4A 52mΩ@4.5V
Q9: DMG1012UW; SOT-323_SC-70; Part Description MOSFET N Channel 20V 1A 450mΩ@4.5V 600m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
R28, R29: 1M; R_0402_1005Metric; Part Description Resistor 62.5mW ±1% 1MΩ
TP5: 3V3; TestPoint_Pad_D1.0mm
TP10: 3V3D; TestPoint_Pad_D1.0mm
U6: XC6220; SOT-23-5; Part Description LDO Voltage Regulators 1A

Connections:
+3V3: C26.1, Q8.2 (S), R28.1, TP5.1, U6.5 (VOUT); also elsewhere on the board
+BATT: C25.1, U6.1 (VIN); also elsewhere on the board
/+3V3D: C24.1, Q8.3 (D), TP10.1; also elsewhere on the board
/Main Controller/DISPLAY_EN: Q9.1 (G), R29.1; also elsewhere on the board
/Power Regulator/LDO_EN: U6.3 (CE); also elsewhere on the board
GND: C24.2, C25.2, C26.2, Q9.2 (S), R29.2, U6.2 (VSS); also elsewhere on the board
unnamed: Q8.1 (G), Q9.3 (D), R28.2

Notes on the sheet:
Use better LDO with lower Iq
Max 1000mA
Display Power
Sheets Connection
Power Regulator

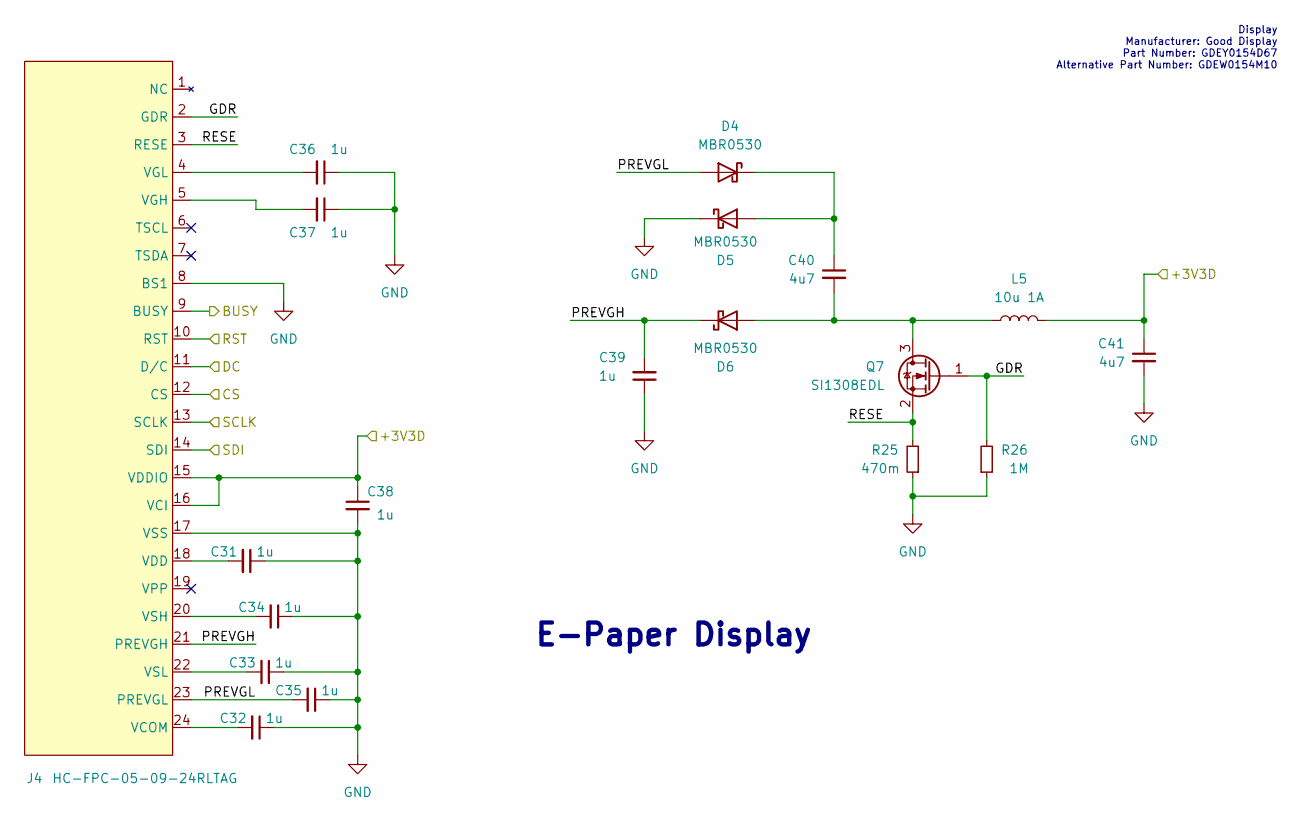
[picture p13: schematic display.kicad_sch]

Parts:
C31, C32, C33, C34, C35, C36, C37, C38, C39: 1u; C_0402_1005Metric; Part Description Ceramic Capacitors 50V 1uF X5R ±10%
C40, C41: 4u7; C_0603_1608Metric; Part Description Ceramic Capacitors 25V 4.7uF X5R ±10%
D4, D5, D6: MBR0530; D_SOD-123; Part Description Schottky Barrier Diodes 30V 430mV@500mA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
J4: HC-FPC-05-09-24RLTAG; FPC-SMD_24P-P0.50_HC-FPC-05-09-24RLTAG; Part Description FFC & FPC Connectors Clamshell 24P Bott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
L5: 10u 1A; L_Changjiang_FNR4012S; Part Description Power Inductors 1A 10uH ±20% 1.1A SMD,4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
Q7: SI1308EDL; SOT-323_SC-70; Part Description MOSFET N Channel 30V 1.4A 132mΩ@10V,1.4A
R25: 470m; R_0402_1005Metric; Part Description Resistor 125mW ±1% 470mΩ
R26: 1M; R_0402_1005Metric; Part Description Resistors 100mW ±1% 1MΩ

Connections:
/+3V3D: C38.1, C41.1, J4.15 (VDDIO), J4.16 (VCI), L5.1; also elsewhere on the board
/Display/BUSY: J4.9 (BUSY); also elsewhere on the board
/Display/CS: J4.12 (CS); also elsewhere on the board
/Display/DC: J4.11 (D/C); also elsewhere on the board
/Display/GDR: J4.2 (GDR), Q7.1 (G), R26.2
/Display/PREVGH: C39.2, D6.1 (K), J4.21 (PREVGH)
/Display/PREVGL: C35.2, D4.2 (A), J4.23 (PREVGL)
/Display/RESE: J4.3 (RESE), Q7.2 (S), R25.2
/Display/RST: J4.10 (RST); also elsewhere on the board
/Display/SCLK: J4.13 (SCLK); also elsewhere on the board
/Display/SDI: J4.14 (SDI); also elsewhere on the board
GND: C31.1, C32.1, C33.1, C34.1, C35.1, C36.1, C37.1, C38.2, C39.1, C41.2, D5.1 (K), J4.8 (BS1), J4.17 (VSS), R25.1, R26.1; also elsewhere on the board
unnamed: C40.1, D4.1 (K), D5.2 (A)
unnamed: C40.2, D6.2 (A), L5.2, Q7.3 (D)
unnamed: C32.2, J4.24 (VCOM)
unnamed: C31.2, J4.18 (VDD)
unnamed: C37.2, J4.5 (VGH)
unnamed: C36.2, J4.4 (VGL)
unnamed: C34.2, J4.20 (VSH)
unnamed: C33.2, J4.22 (VSL)

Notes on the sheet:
Display Manufacturer: Good Display Part Number: GDEY0154D67 Alternative Part Number: GDEW0154M10
E-Paper Display

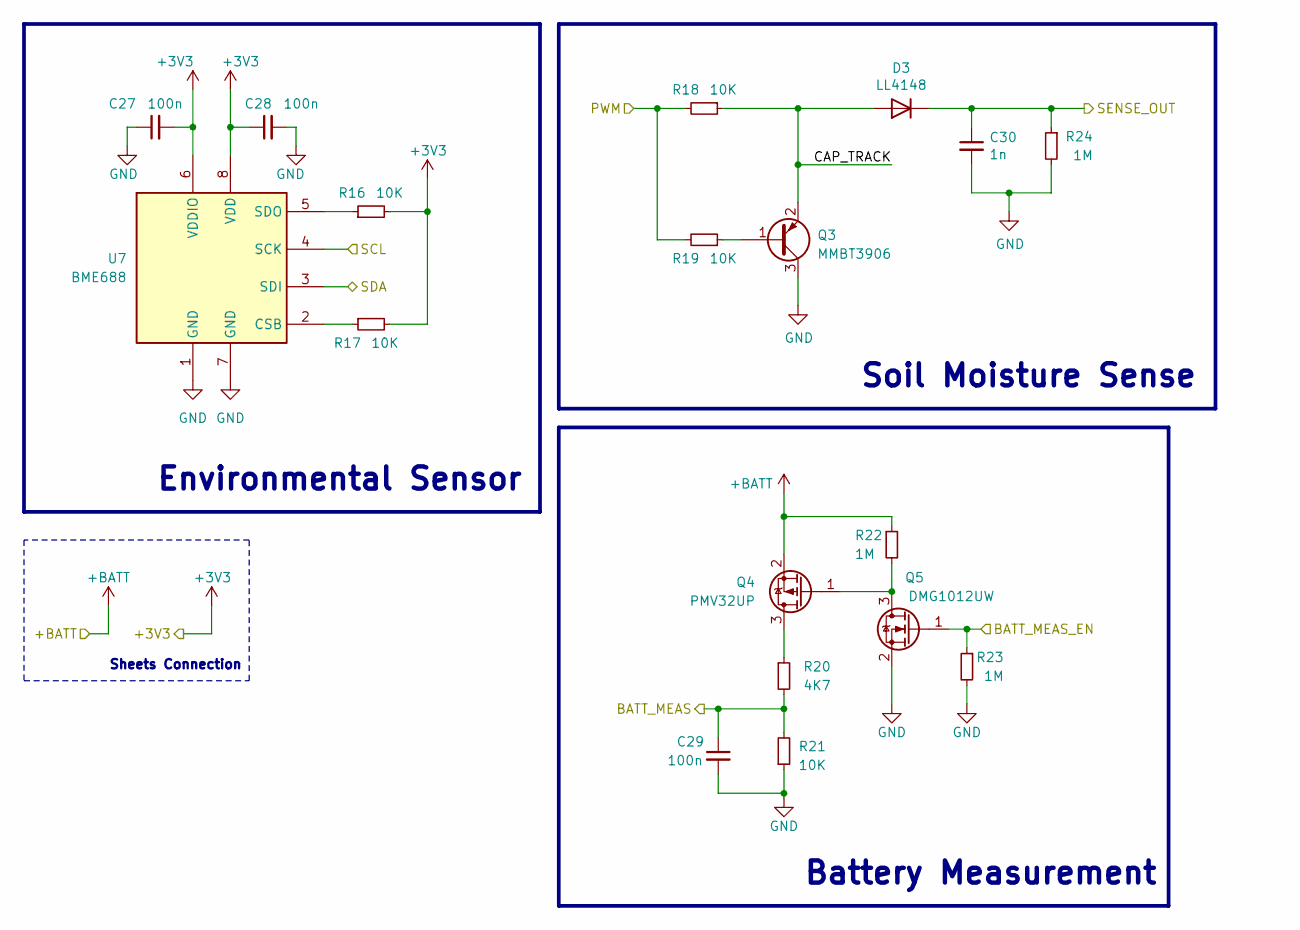
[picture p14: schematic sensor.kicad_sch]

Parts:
C27, C28, C29: 100n; C_0402_1005Metric; Part Description Ceramic Capacitor 16V 100nF X7R ±10%
C30: 1n; C_0402_1005Metric; Part Description Ceramic Capacitors 50V 1nF X7R ±10%
D3: LL4148; D_MiniMELF; Part Description Switching Diode 75V 500mW 1V@10mA 4ns 0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
Q3: MMBT3906; SOT-23; Part Description Bipolar Transistors 40V 200mW 100@10mA,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
Q4: PMV32UP; SOT-23; Part Description MOSFET P Channel 20V 4A 52mΩ@4.5V
Q5: DMG1012UW; SOT-323_SC-70; Part Description MOSFET N Channel 20V 1A 450mΩ@4.5V 600m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
R16, R17, R18, R19, R21: 10K; R_0402_1005Metric; Part Description Resistors 62.5mW ±1% 10kΩ
R20: 4K7; R_0402_1005Metric; Part Description Resistor 62.5mW ±1% 4.7kΩ
R22, R23, R24: 1M; R_0402_1005Metric; Part Description Resistor 62.5mW ±1% 1MΩ
U7: BME688; BME680-PSON80P300X300X100-8N; Part Description Gas, Humidity, Pressure, Temperature Se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

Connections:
+3V3: C27.2, C28.1, R16.2, R17.2, U7.6 (VDDIO), U7.8 (VDD); also elsewhere on the board
+BATT: Q4.2 (S), R22.1; also elsewhere on the board
/Main Controller/BATT_MEAS: C29.1, R20.2, R21.2; also elsewhere on the board
/Main Controller/BATT_MEAS_EN: Q5.1 (G), R23.1; also elsewhere on the board
/Main Controller/PWM: R18.2, R19.2; also elsewhere on the board
/Main Controller/SENSE_OUT: C30.1, D3.1 (K), R24.1; also elsewhere on the board
/SCL: U7.4 (SCK); also elsewhere on the board
/SDA: U7.3 (SDI); also elsewhere on the board
/Sensor/CAP_TRACK: D3.2 (A), Q3.2 (E), R18.1
GND: C27.1, C28.2, C29.2, C30.2, Q3.3 (C), Q5.2 (S), R21.1, R23.2, R24.2, U7.1 (GND), U7.7 (GND); also elsewhere on the board
unnamed: Q3.1 (B), R19.1
unnamed: Q4.3 (D), R20.1
unnamed: Q4.1 (G), Q5.3 (D), R22.2
unnamed: R17.1, U7.2 (CSB)
unnamed: R16.1, U7.5 (SDO)

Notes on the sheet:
Sheets Connection
Soil Moisture Sense
Battery Measurement
Environmental Sensor

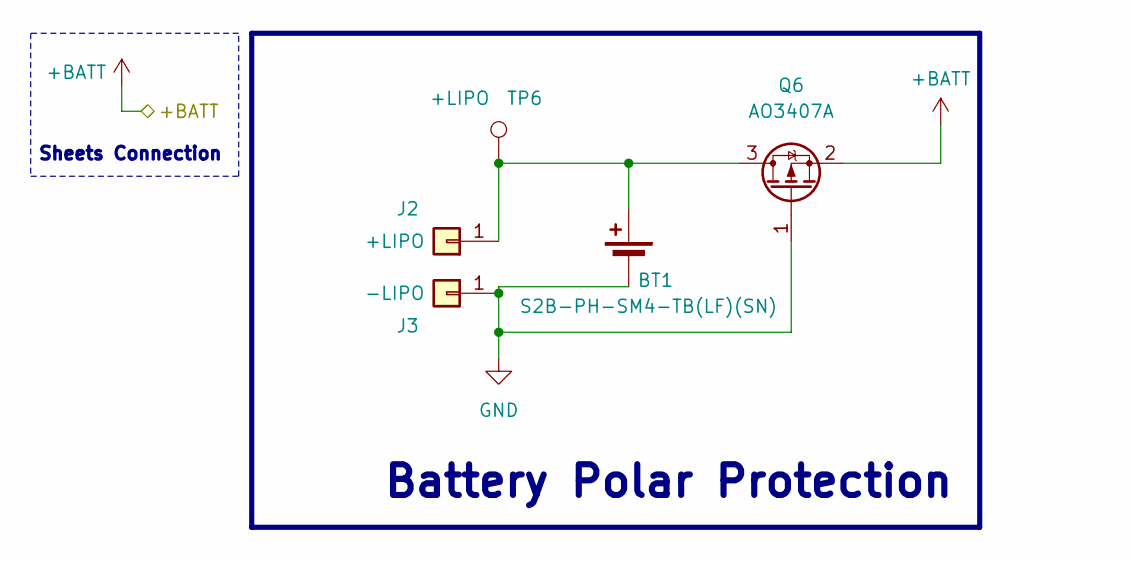
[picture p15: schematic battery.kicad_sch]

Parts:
BT1: S2B-PH-SM4-TB(LF)(SN); JST_PH_S2B-PH-SM4-TB_1x02-1MP_P2.00mm_Horizontal; Part Description Wire To Board Connector 1x2P PH 2mm Mal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
J2: +LIPO; TestPoint_THTPad_D1.0mm_Drill0.5mm; Part Description On-board Pad
J3: -LIPO; TestPoint_THTPad_D1.0mm_Drill0.5mm; Part Description On-board Pad
Q6: AO3407A; SOT-23; Part Description MOSFET P Channel 30V 4.3A 48mΩ@10V,4.3A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
TP6: +LIPO; TestPoint_Pad_D1.0mm

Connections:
+BATT: Q6.2 (S); also elsewhere on the board
GND: BT1.2 (-), J3.1, Q6.1 (G); also elsewhere on the board
unnamed: BT1.1 (+), J2.1, Q6.3 (D), TP6.1

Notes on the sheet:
Battery Polar Protection
Sheets Connection

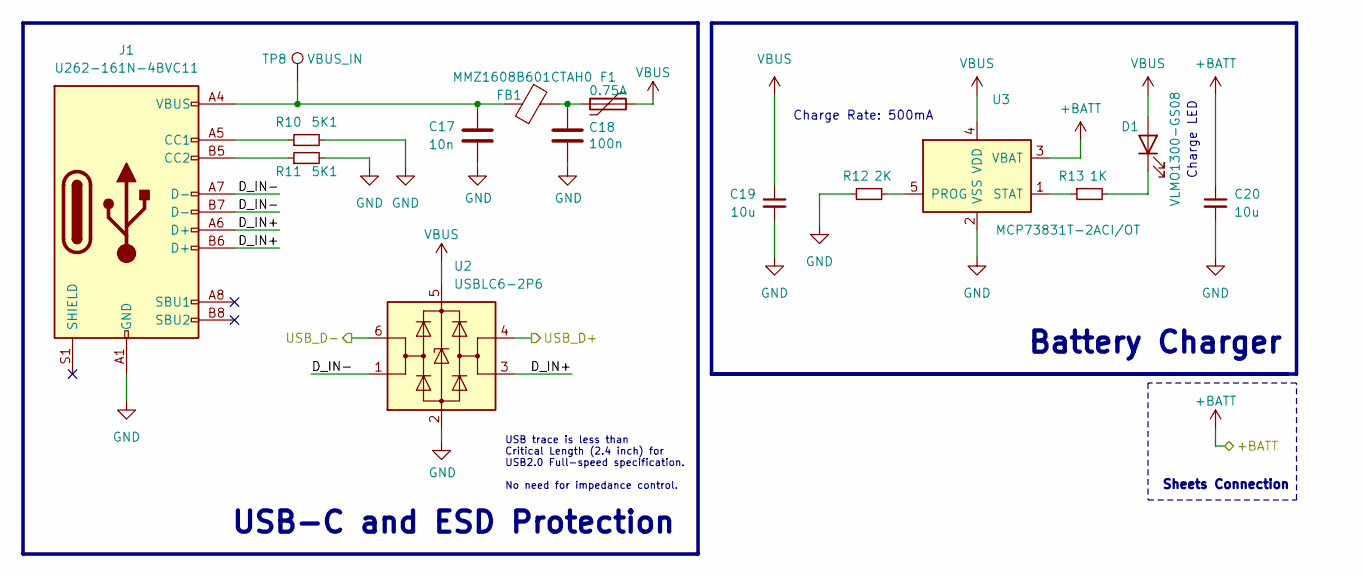
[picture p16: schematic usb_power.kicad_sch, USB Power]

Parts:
C17: 10n; C_0402_1005Metric; Part Description Ceramic Capacitors 16V 10nF X7R ±10%
C18: 100n; C_0402_1005Metric; Part Description Ceramic Capacitor 16V 100nF X7R ±10%
C19, C20: 10u; C_0603_1608Metric; Part Description Ceramic Capacitor 10V 10uF X5R ±10% 0603
D1: VLMO1300-GS08; LED_0603_1608Metric; Part Description Orange 2V 20mA
F1: 0.75A; Fuse_0805_2012Metric; Part Description Resettable Fuses 6V 750mA 40A 1.5A
FB1: MMZ1608B601CTAH0; L_0603_1608Metric; Part Description Ferrite Beads 400mΩ ±25% 600Ω@100MHz
J1: U262-161N-4BVC11; USB_C_Receptacle_XKB_U262-16XN-4BVC11; Part Description USB Connectors Type-C 3A USB 3.1 16P
R10, R11: 5K1; R_0402_1005Metric; Part Description Resistor 62.5mW ±1% 5.1kΩ
R12: 2K; R_0402_1005Metric; Part Description Resistor 62.5mW ±1% 2kΩ
R13: 1K; R_0402_1005Metric; Part Description Resistor 62.5mW ±1% 1kΩ
TP8: VBUS_IN; TestPoint_Pad_D1.0mm
U2: USBLC6-2P6; SOT-666; Part Description ESD Protection 6V 17V 2 Unidirectional 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
U3: MCP73831T-2ACI/OT; SOT-23-5; Part Description Battery Management IC 6V LiPoly 1500mA

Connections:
+BATT: C20.1, U3.3 (VBAT); also elsewhere on the board
/Main Controller/USB_D+: U2.4 (I/O2); also elsewhere on the board
/Main Controller/USB_D-: U2.6 (I/O1); also elsewhere on the board
/USB Power/D_IN+: J1.A6 (D+), J1.B6 (D+), U2.3 (I/O2)
/USB Power/D_IN-: J1.A7 (D-), J1.B7 (D-), U2.1 (I/O1)
GND: C17.2, C18.2, C19.2, C20.2, J1.A1 (GND), J1.A12 (GND), J1.B1 (GND), J1.B12 (GND), R10.2, R11.2, R12.2, U2.2 (GND), U3.2 (VSS); also elsewhere on the board
unnamed: C17.1, FB1.1, J1.A4 (VBUS), J1.A9 (VBUS), J1.B4 (VBUS), J1.B9 (VBUS), TP8.1
unnamed: C18.1, F1.1, FB1.2
unnamed: D1.1 (K), R13.2
unnamed: J1.A5 (CC1), R10.1
unnamed: J1.B5 (CC2), R11.1
unnamed: R12.1, U3.5 (PROG)
unnamed: R13.1, U3.1 (STAT)
VBUS: C19.1, D1.2 (A), F1.2, U2.5 (VBUS), U3.4 (VDD)

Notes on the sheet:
Sheets Connection
Charge Rate: 500mA
Battery Charger
USB-C and ESD Protection
Charge LED
USB trace is less than Critical Length (2.4 inch) for USB2.0 Full-speed specification. No need for impedance control.

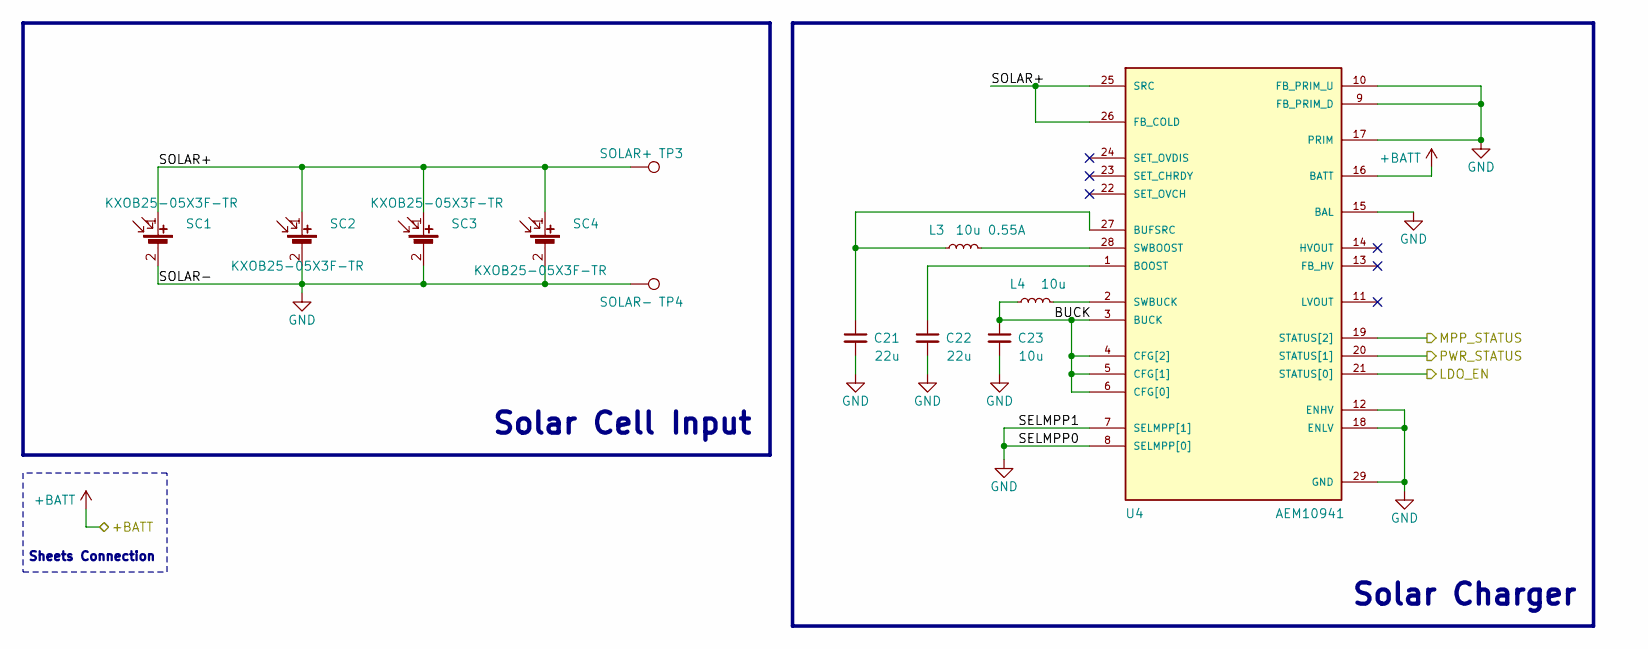
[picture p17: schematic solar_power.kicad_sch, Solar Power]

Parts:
C21, C22: 22u; C_0603_1608Metric; Part Description Ceramic Capacitors 10V 22uF X5R ±20%
C23: 10u; C_0603_1608Metric; Part Description Ceramic Capacitor 10V 10uF X5R ±10%
L3: 10u 0.55A; IND_LPS4012-103MRB; Part Description Power Inductors - SMD 10uH Shld 20% 1.1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
L4: 10u; L_0603_1608Metric; Part Description Power Inductors 10uH ±20% 90mA 1.05Ω
SC1, SC2, SC3, SC4: KXOB25-05X3F-TR; KXOB25-05X3F; Part Description Solar Cell G3 Thin 2.07V 30.7MW
TP3: SOLAR+; TestPoint_Pad_D1.0mm
TP4: SOLAR-; TestPoint_Pad_D1.0mm
U4: AEM10941; QFN-28-1EP_5x5mm_P0.5mm_EP3.35x3.35mm; Part Description PMIC IC - Photovoltaic Energy Harvestin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

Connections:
+BATT: U4.16 (BATT); also elsewhere on the board
/Main Controller/MPP_STATUS: U4.19 (STATUS[2]); also elsewhere on the board
/Main Controller/PWR_STATUS: U4.20 (STATUS[1]); also elsewhere on the board
/Power Regulator/LDO_EN: U4.21 (STATUS[0]); also elsewhere on the board
/Solar Power/BUCK: C23.1, L4.1, U4.3 (BUCK), U4.4 (CFG[2]), U4.5 (CFG[1]), U4.6 (CFG[0])
/Solar Power/SOLAR+: SC1.1 (+), SC2.1 (+), SC3.1 (+), SC4.1 (+), TP3.1, U4.25 (SRC), U4.26 (FB_COLD)
GND: C21.2, C22.2, C23.2, SC1.2 (-), SC2.2 (-), SC3.2 (-), SC4.2 (-), TP4.1, U4.7 (SELMPP[1]), U4.8 (SELMPP[0]), U4.9 (FB_PRIM_D), U4.10 (FB_PRIM_U), U4.12 (ENHV), U4.15 (BAL), U4.17 (PRIM), U4.18 (ENLV), U4.29 (GND); also elsewhere on the board
unnamed: C22.1, U4.1 (BOOST)
unnamed: C21.1, L3.1, U4.27 (BUFSRC)
unnamed: L3.2, U4.28 (SWBOOST)
unnamed: L4.2, U4.2 (SWBUCK)

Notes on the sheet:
Solar Cell Input
Sheets Connection
Solar Charger

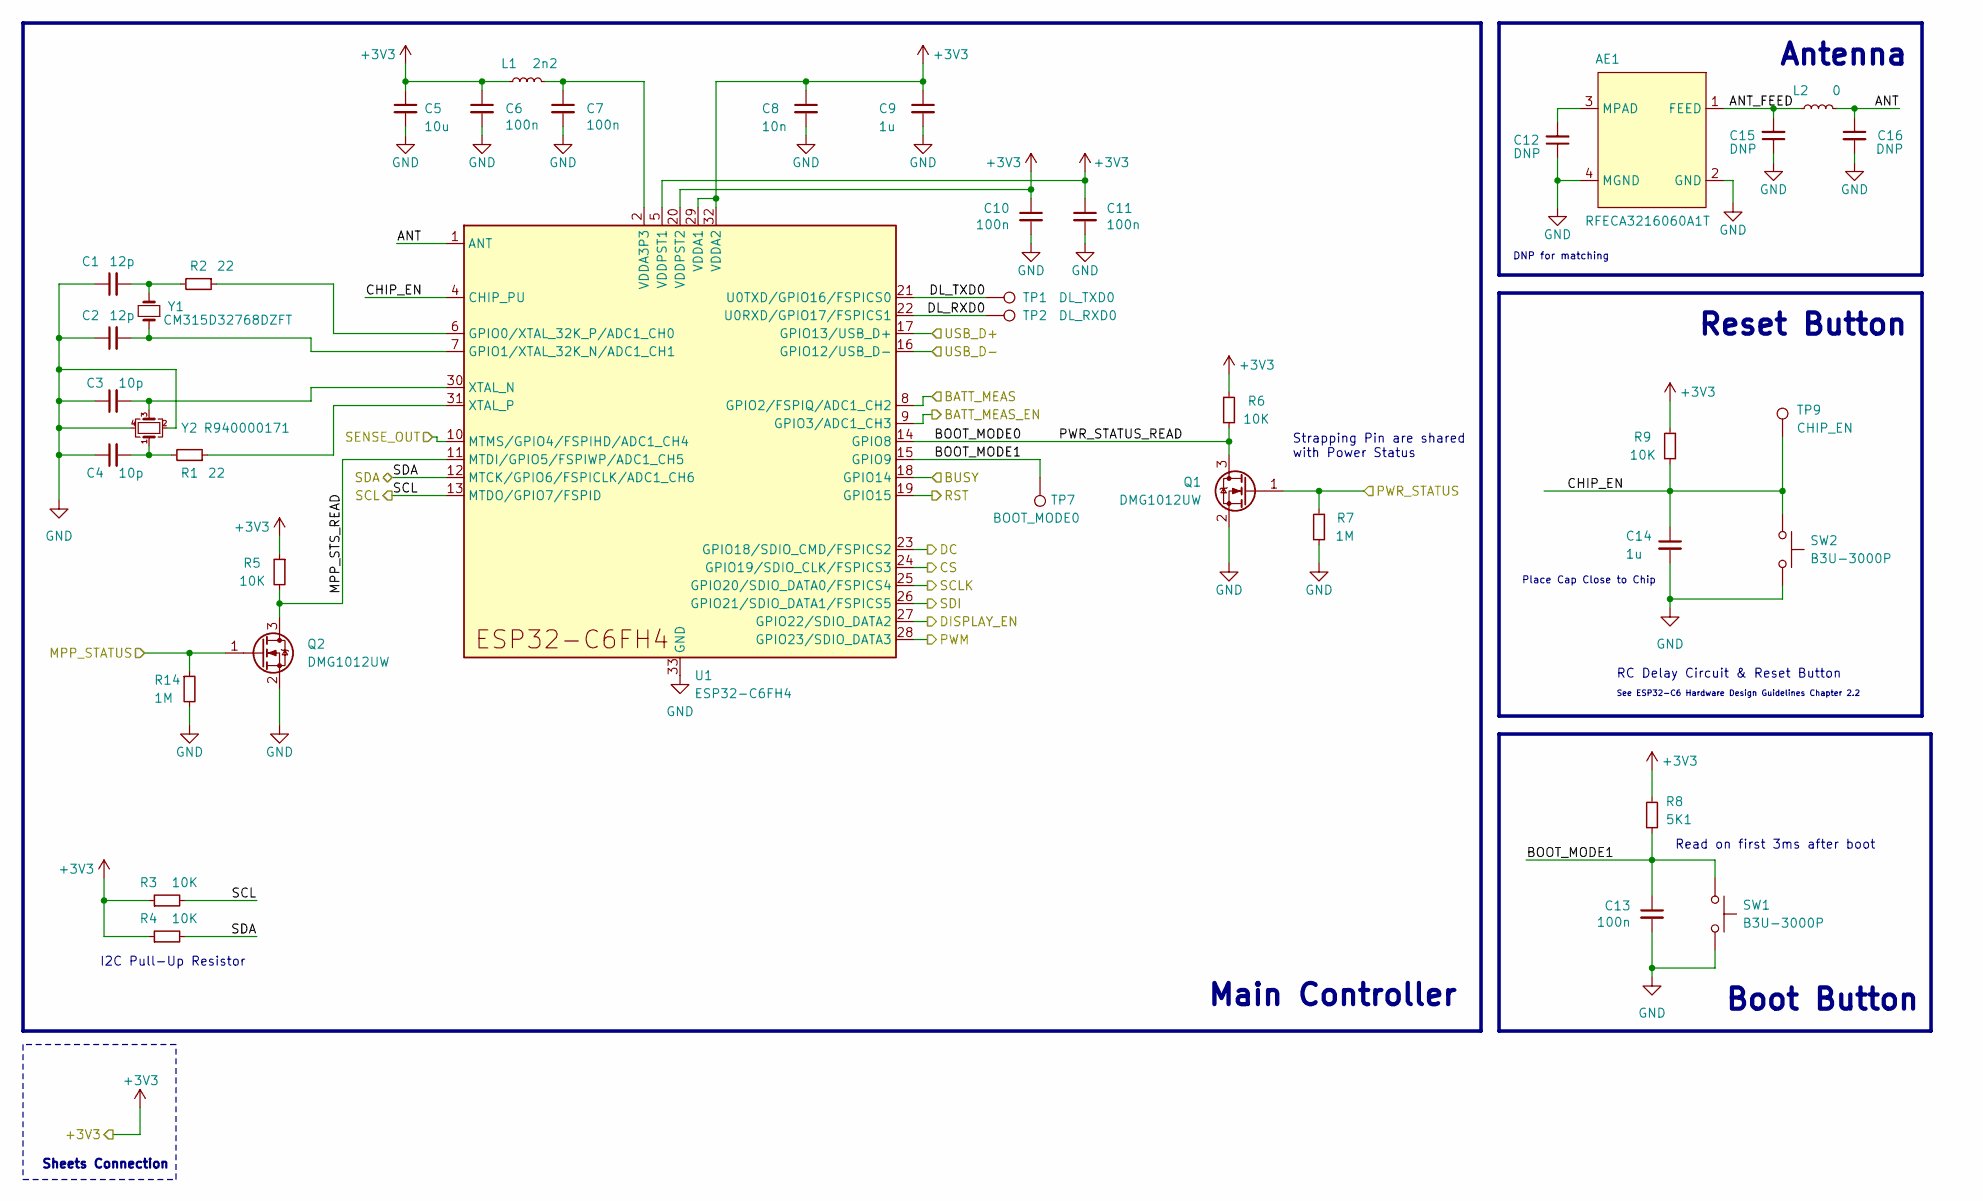
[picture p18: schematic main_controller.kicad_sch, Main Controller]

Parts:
AE1: RFECA3216060A1T; Part Description Chip RF Antenna 2.4GHz 2dBi
C1, C2: 12p; C_0402_1005Metric; Part Description Ceramic Capacitors 50V 12pF C0G ±1%
C3, C4: 10p; C_0402_1005Metric; Part Description Ceramic Capacitors 50V 10pF C0G ±1%
C5: 10u; C_0603_1608Metric; Part Description Ceramic Capacitor 10V 10uF X5R ±10% 0603
C6, C7, C10, C11, C13: 100n; C_0402_1005Metric; Part Description Ceramic Capacitor 16V 100nF X7R ±10%
C8: 10n; C_0402_1005Metric; Part Description Ceramic Capacitors 16V 10nF X7R ±10%
C9, C14: 1u; C_0402_1005Metric; Part Description Ceramic Capacitors 10V 1uF X7R ±10%
C12, C15, C16: DNP; C_0402_1005Metric
L1: 2n2; L_0402_1005Metric; Part Description Power Inductors 2.53A 2.2nH ±2%
L2: 0; L_0402_1005Metric; Part Description Resistor 62.5mW ±1% 0Ω
Q1, Q2: DMG1012UW; SOT-323_SC-70; Part Description MOSFET N Channel 20V 1A 450mΩ@4.5V,600m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
R1, R2: 22; R_0402_1005Metric; Part Description Resistor 62.5mW ±1% 22Ω
R3, R4, R5, R6, R9: 10K; R_0402_1005Metric; Part Description Resistors 62.5mW ±1% 10kΩ
R7, R14: 1M; R_0402_1005Metric; Part Description Resistor 62.5mW ±1% 1MΩ
R8: 5K1; R_0402_1005Metric; Part Description Resistor 62.5mW ±1% 5.1kΩ
SW1, SW2: B3U-3000P; SW_SPST_B3U-3000P; Part Description Tactile Switches NO 50mA 100MΩ 12V 1.59N
TP1: DL_TXD0; TestPoint_Pad_D1.0mm
TP2: DL_RXD0; TestPoint_Pad_D1.0mm
TP7: BOOT_MODE0; TestPoint_Pad_D1.0mm
TP9: CHIP_EN; TestPoint_Pad_D1.0mm
U1: ESP32-C6FH4; QFN-32-1EP_5x5mm_P0.5mm_EP3.6x3.6mm; Part Description Wireless SOC Bluetooth, WiFi Bluetooth 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
Y1: CM315D32768DZFT; Crystal_SMD_3215-2Pin_3.2x1.5mm; Part Description Crystals 32.768kHz 12.5pF ±20ppm
Y2: R940000171; Crystal_SMD_2016-4Pin_2.0x1.6mm; Part Description Crystals 40MHz 9pF ±10ppm

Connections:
+3V3: C5.1, C6.1, C8.1, C9.1, C10.1, C11.1, L1.1, R3.1, R4.1, R5.1, R6.1, R8.2, R9.1, U1.5 (VDDPST1), U1.20 (VDDPST2), U1.29 (VDDA1), U1.32 (VDDA2); also elsewhere on the board
/Display/BUSY: U1.18 (GPIO14); also elsewhere on the board
/Display/CS: U1.24 (GPIO19/SDIO_CLK/FSPICS3); also elsewhere on the board
/Display/DC: U1.23 (GPIO18/SDIO_CMD/FSPICS2); also elsewhere on the board
/Display/RST: U1.19 (GPIO15); also elsewhere on the board
/Display/SCLK: U1.25 (GPIO20/SDIO_DATA0/FSPICS4); also elsewhere on the board
/Display/SDI: U1.26 (GPIO21/SDIO_DATA1/FSPICS5); also elsewhere on the board
/Main Controller/ANT: C16.1, L2.2, U1.1 (ANT)
/Main Controller/ANT_FEED: AE1.1 (FEED), C15.2, L2.1
/Main Controller/BATT_MEAS: U1.8 (GPIO2/FSPIQ/ADC1_CH2); also elsewhere on the board
/Main Controller/BATT_MEAS_EN: U1.9 (GPIO3/ADC1_CH3); also elsewhere on the board
/Main Controller/BOOT_MODE0: Q1.3 (D), R6.2, U1.14 (GPIO8)
/Main Controller/BOOT_MODE1: C13.1, R8.1, SW1.1, TP7.1, U1.15 (GPIO9)
/Main Controller/CHIP_EN: C14.1, R9.2, SW2.1, TP9.1, U1.4 (CHIP_PU)
/Main Controller/DISPLAY_EN: U1.27 (GPIO22/SDIO_DATA2); also elsewhere on the board
/Main Controller/DL_RXD0: TP2.1, U1.22 (U0RXD/GPIO17/FSPICS1)
/Main Controller/DL_TXD0: TP1.1, U1.21 (U0TXD/GPIO16/FSPICS0)
/Main Controller/MPP_STATUS: Q2.1 (G), R14.1; also elsewhere on the board
/Main Controller/MPP_STS_READ: Q2.3 (D), R5.2, U1.11 (MTDI/GPIO5/FSPIWP/ADC1_CH5)
/Main Controller/PWM: U1.28 (GPIO23/SDIO_DATA3); also elsewhere on the board
/Main Controller/PWR_STATUS: Q1.1 (G), R7.1; also elsewhere on the board
/Main Controller/SENSE_OUT: U1.10 (MTMS/GPIO4/FSPIHD/ADC1_CH4); also elsewhere on the board
/Main Controller/USB_D+: U1.17 (GPIO13/USB_D+); also elsewhere on the board
/Main Controller/USB_D-: U1.16 (GPIO12/USB_D-); also elsewhere on the board
/SCL: R3.2, U1.13 (MTDO/GPIO7/FSPID); also elsewhere on the board
/SDA: R4.2, U1.12 (MTCK/GPIO6/FSPICLK/ADC1_CH6); also elsewhere on the board
GND: AE1.2 (GND), AE1.4 (MGND), C1.1, C2.1, C3.1, C4.1, C5.2, C6.2, C7.2, C8.2, C9.2, C10.2, C11.2, C12.1, C13.2, C14.2, C15.1, C16.2, Q1.2 (S), Q2.2 (S), R7.2, R14.2, SW1.2, SW2.2, U1.33 (GND), Y2.2, Y2.4; also elsewhere on the board
unnamed: AE1.3 (MPAD), C12.2
unnamed: C1.2, R2.2, Y1.2
unnamed: C4.2, R1.2, Y2.1
unnamed: C7.1, L1.2, U1.2 (VDDA3P3), U1.3 (VDDA3P3)
unnamed: R2.1, U1.6 (GPIO0/XTAL_32K_P/ADC1_CH0)
unnamed: C2.2, U1.7 (GPIO1/XTAL_32K_N/ADC1_CH1), Y1.1
unnamed: C3.2, U1.30 (XTAL_N), Y2.3
unnamed: R1.1, U1.31 (XTAL_P)

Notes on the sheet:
Place Cap Close to Chip
Reset Button
Antenna
DNP for matching
Main Controller
Sheets Connection
Boot Button
See ESP32-C6 Hardware Design Guidelines Chapter 2.2
RC Delay Circuit & Reset Button
Read on first 3ms after boot
I2C Pull-Up Resistor
Strapping Pin are shared with Power Status

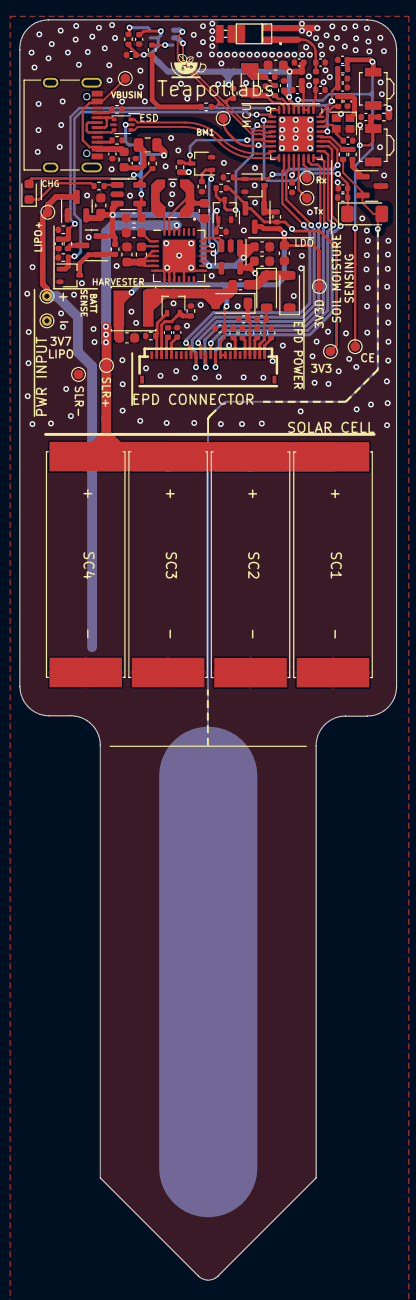
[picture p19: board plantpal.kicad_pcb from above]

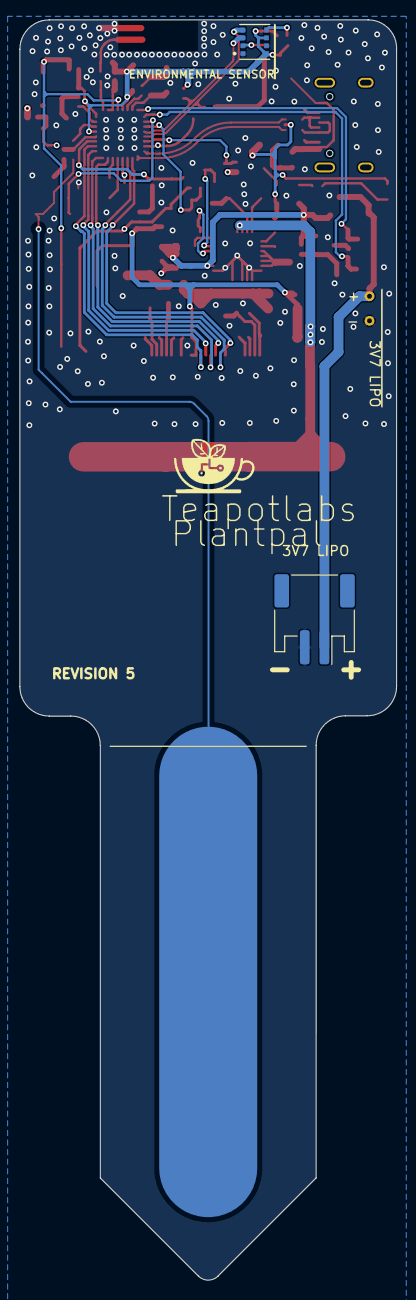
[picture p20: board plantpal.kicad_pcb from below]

Board: 4 copper layers, 38.4 x 128.5 mm, 119 parts (2 on the bottom side), 74 nets.

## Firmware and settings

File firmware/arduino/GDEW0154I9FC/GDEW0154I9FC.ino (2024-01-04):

#include <SPI.h>
#include"Ap_29demo.h"

// // ESP32-C6
// #define A14 3 //BUSY
// #define A15 2 //RES 
// #define A16 11 //DC   
// #define A17 10 //CS 

// static const uint8_t SS    = 18;
// static const uint8_t MOSI  = 19;
// static const uint8_t MISO  = 20;
// static const uint8_t SCK   = 21;

// Plantpal
// #define A14 14 //BUSY
// #define A15 15 //RES 
// #define A16 18 //DC   
// #define A17 19 //CS 

// static const uint8_t SS    = 18;
// static const uint8_t MOSI  = 21;
// static const uint8_t MISO  = 19;
// static const uint8_t SCK   = 20;

//IO settings
int BUSY_Pin = 14; 
int RES_Pin = 15; 
int DC_Pin = 18; 
int CS_Pin = 19; 

#define EPD_W21_CS_0 digitalWrite(CS_Pin,LOW)
#define EPD_W21_CS_1 digitalWrite(CS_Pin,HIGH)
#define EPD_W21_DC_0  digitalWrite(DC_Pin,LOW)
#define EPD_W21_DC_1  digitalWrite(DC_Pin,HIGH)
#define EPD_W21_RST_0 digitalWrite(RES_Pin,LOW)
#define EPD_W21_RST_1 digitalWrite(RES_Pin,HIGH)
#define isEPD_W21_BUSY digitalRead(BUSY_Pin)
////////FUNCTION//////
void SPI_Write(unsigned char value);
void EPD_W21_WriteDATA(unsigned char command);
void EPD_W21_WriteCMD(unsigned char command);
//EPD
void EPD_W21_Init(void);
void EPD_init(void);
void EPD_sleep(void);
void EPD_refresh(void);
void lcd_chkstatus(void);
void PIC_display_Clean(void);
void PIC_display(const unsigned char* picData);

SPIClass * fspi = NULL;
void setup() {
   Serial.begin(115200);
   pinMode(BUSY_Pin, INPUT); 
   pinMode(RES_Pin, OUTPUT);  
   pinMode(DC_Pin, OUTPUT);    
   pinMode(CS_Pin, OUTPUT);   
   //SPI
  //  SPI.beginTransaction(SPISettings(10000000, MSBFIRST, SPI_MODE0)); 
  //  SPI.begin ();  

   fspi = new SPIClass(FSPI);
   fspi->beginTransaction(SPISettings(10000000, MSBFIRST, SPI_MODE0));  
   fspi->begin(20, 16, 21, 17); //SCLK, MISO, MOSI, SS
}
//Tips//
/*When the electronic paper is refreshed in full screen, the picture flicker is a normal phenomenon, and the main function is to clear the display afterimage in the previous picture.
  When the local refresh is performed, the screen does not flash.*/
/*When you need to transplant the driver, you only need to change the corresponding IO. The BUSY pin is the input mode and the others are the output mode. */

void loop() {
  while(1)
  {

    Serial.println("Test Picture 1");
    EPD_init(); //EPD init
    PIC_display(gImage_1);//EPD_picture1
    EPD_sleep();//EPD_sleep,Sleep instruction is necessary, please do not delete!!!
    delay(2000); //2s  
    
    Serial.println("Test Picture 2");
    //PICTURE2
    EPD_init(); //EPD init
    PIC_display(gImage_2);//EPD_picture1
    EPD_sleep();//EPD_sleep,Sleep instruction is necessary, please do not delete!!!
     delay(2000); //2s  
    
    Serial.println("Test Clean");
    //PICTURE Clean
     EPD_init(); //EPD init
    PIC_display_Clean();
    EPD_sleep();//EPD_sleep,Sleep instruction is necessary, please do not delete!!!
    while(1); 

  }


}

//////////////////////SPI///////////////////////////////////

void SPI_Write(unsigned char value)                                    
{                                                           
    fspi->transfer(value);

}

void EPD_W21_WriteCMD(unsigned char command)
{
  EPD_W21_CS_0;                   
  EPD_W21_DC_0;   // command write
  SPI_Write(command);
  EPD_W21_CS_1;
}
void EPD_W21_WriteDATA(unsigned char command)
{
  EPD_W21_CS_0;                   
  EPD_W21_DC_1;   // command write
  SPI_Write(command);
  EPD_W21_CS_1;
}


/////////////////EPD settings Functions/////////////////////
void EPD_W21_Init(void)
{
  unsigned char i;
  for(i=0;i<3;i++) //Reset, three times to prevent the secondary electricity cannot be started
  {
    EPD_W21_RST_0;    // Module reset
    delay(10);//At least 10ms delay 
    EPD_W21_RST_1;
    delay(10);//At least 10ms delay 
  }
}
void EPD_init(void)
{
    EPD_W21_Init(); //Electronic paper IC reset
    
    EPD_W21_WriteCMD(0x04);  
    lcd_chkstatus();//waiting for the electronic paper IC to release the idle signal

    EPD_W21_WriteCMD(0x00);     //panel setting
    EPD_W21_WriteDATA(0x1f);    //LUT from OTP£¬KW-BF   KWR-AF  BWROTP 0f BWOTP 1f

    EPD_W21_WriteCMD(0x61);     //resolution setting
    EPD_W21_WriteDATA (0x98);   //152        
    EPD_W21_WriteDATA (0x00);   //152
    EPD_W21_WriteDATA (0x98);
  
    EPD_W21_WriteCMD(0X50);     //VCOM AND DATA INTERVAL SETTING      
    EPD_W21_WriteDATA(0x97);    //WBmode:VBDF 17|D7 VBDW 97 VBDB 57   WBRmode:VBDF F7 VBDW 77 VBDB 37  VBDR B7
}
void EPD_refresh(void)
{
    EPD_W21_WriteCMD(0x12);     //DISPLAY REFRESH   
    delay(10);          //!!!The delay here is necessary, 200uS at least!!!     
    lcd_chkstatus();
} 
void EPD_sleep(void)
{
    EPD_W21_WriteCMD(0X02);   //power off
    lcd_chkstatus();          //waiting for the electronic paper IC to release the idle signal
    //Part2 Increase the time delay
    delay(1000);      //Power off time delay, this is  necessary!!!     
    EPD_W21_WriteCMD(0X07);   //deep sleep
    EPD_W21_WriteDATA(0xA5);
}

void PIC_display(const unsigned char* picData)
{
    unsigned int i;
    EPD_W21_WriteCMD(0x10);        //Transfer old data
    for(i=0;i<2888;i++)      
    EPD_W21_WriteDATA(0xff); 
  
    EPD_W21_WriteCMD(0x13);        //Transfer new data
    for(i=0;i<2888;i++)      
     EPD_W21_WriteDATA(pgm_read_byte(&picData[i]));

       //Refresh
    EPD_W21_WriteCMD(0x12);   //DISPLAY REFRESH   
    delay(10);    //!!!The delay here is necessary, 200uS at least!!!     
    lcd_chkstatus();          //waiting for the electronic paper IC to release the idle signal

}

void PIC_display_Clean(void)
{
    unsigned int i;
    EPD_W21_WriteCMD(0x10);        //Transfer old data
    for(i=0;i<2888;i++)       
  {
    EPD_W21_WriteDATA(0xff);
  }
  
    EPD_W21_WriteCMD(0x13);        //Transfer new data
    for(i=0;i<2888;i++)       
  {
    EPD_W21_WriteDATA(0xff);
  }
     //Refresh
    EPD_W21_WriteCMD(0x12);   //DISPLAY REFRESH   
    delay(10);    //!!!The delay here is necessary, 200uS at least!!!     
    lcd_chkstatus();          //waiting for the electronic paper IC to release the idle signal

}
void lcd_chkstatus(void)
{
  while(1)
  {   //=0 BUSY
     if(isEPD_W21_BUSY==1) break;
  }                  
}

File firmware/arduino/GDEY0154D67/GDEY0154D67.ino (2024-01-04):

#include <SPI.h>
//EPD
#include "Display_EPD_W21_spi.h"
#include "Display_EPD_W21.h"
#include "Ap_29demo.h"  

// ESP32-C3 DevKit M1
// #define A14 0 //BUSY
// #define A15 1 //RES 
// #define A16 3 //DC   
// #define A17 10 //CS 

// static const uint8_t SS    = 7;
// static const uint8_t MOSI  = 6;
// static const uint8_t MISO  = 5;
// static const uint8_t SCK   = 4;

// // ESP32-C6
// #define A14 3 //BUSY
// #define A15 2 //RES 
// #define A16 11 //DC   
// #define A17 10 //CS 

// static const uint8_t SS    = 18;
// static const uint8_t MOSI  = 19;
// static const uint8_t MISO  = 20;
// static const uint8_t SCK   = 21;

// // ESP32-C6 DevKit Plantpal
// #define A14 3 //BUSY
// #define A15 2 //RES 
// #define A16 11 //DC   
// #define A17 10 //CS 

// static const uint8_t SS    = 18;
// static const uint8_t MOSI  = 21;
// static const uint8_t MISO  = 19;
// static const uint8_t SCK   = 20;

// Plantpal
#define A14 14 //BUSY
#define A15 15 //RES 
#define A16 18 //DC   
#define A17 19 //CS 

// static const uint8_t SS    = 18;
// static const uint8_t MOSI  = 21;
// static const uint8_t MISO  = 19;
// static const uint8_t SCK   = 20;

SPIClass * fspi = NULL;
void setup() {
   Serial.begin(115200);
   
   Serial.println("Start Plantpal test!");
   pinMode(A14, INPUT);  //BUSY
   pinMode(A15, OUTPUT); //RES 
   pinMode(A16, OUTPUT); //DC   
   pinMode(A17, OUTPUT); //CS   
   //SPI
  //  SPI.beginTransaction(SPISettings(10000000, MSBFIRST, SPI_MODE0)); 
  //  SPI.begin ();  

   // VSPI
   fspi = new SPIClass(FSPI);
  //  fspi->beginTransaction(SPISettings(10000000, MSBFIRST, SPI_MODE0)); 
   fspi->begin(20, 16, 21, 17); //SCLK, MISO, MOSI, SS
}

//Tips//
/*
1.Flickering is normal when EPD is performing a full screen update to clear ghosting from the previous image so to ensure better clarity and legibility for the new image.
2.There will be no flicker when EPD performs a partial refresh.
3.Please make sue that EPD enters sleep mode when refresh is completed and always leave the sleep mode command. Otherwise, this may result in a reduced lifespan of EPD.
4.Please refrain from inserting EPD to the FPC socket or unplugging it when the MCU is being powered to prevent potential damage.)
5.Re-initialization is required for every full screen update.
6.When porting the program, set the BUSY pin to input mode and other pins to output mode.
// */

// void loop() {
//   delay(500);
//   Serial.print("isEPD_W21_BUSY? ");
//   Serial.println(isEPD_W21_BUSY);
// }

void loop() {
   Serial.println("Start Plantpal Full display test!");
   unsigned char i;
#if 1 //Full screen refresh, fast refresh, and partial refresh demostration.

      EPD_HW_Init(); //Full screen refresh initialization.
      EPD_WhiteScreen_White(); //Clear screen function.
      EPD_DeepSleep(); //Enter the sleep mode and please do not delete it, otherwise it will reduce the lifespan of the screen.
      delay(2000); //Delay for 2s. 
     /************Full display(2s)*******************/
      EPD_HW_Init(); //Full screen refresh initialization.
      EPD_WhiteScreen_ALL(gImage_1); //To Display one image using full screen refresh.
      EPD_DeepSleep(); //Enter the sleep mode and please do not delete it, otherwise it will reduce the lifespan of the screen.
      delay(2000); //Delay for 2s. 
      /************Fast refresh mode(1.5s)*******************/
      EPD_HW_Init_Fast(); //Fast refresh initialization.
      EPD_WhiteScreen_ALL_Fast(gImage_1); //To display one image using fast refresh.
      EPD_DeepSleep(); //Enter the sleep mode and please do not delete it, otherwise it will reduce the lifespan of the screen.
      delay(2000); //Delay for 2s.
      EPD_HW_Init_Fast(); //Fast refresh initialization.
      EPD_WhiteScreen_ALL_Fast(gImage_2); //To display the second image using fast refresh.
      EPD_DeepSleep(); //Enter the sleep mode and please do not delete it, otherwise it will reduce the lifespan of the screen.
      delay(2000); //Delay for 2s.

   Serial.println("Start Plantpal Fast refresh mode test!");
     /************Fast refresh mode(1s)*******************/
  #if 1   //To enable this feature, please change 0 to 1
      /************Onder versions do not support this feature*******************/
      EPD_HW_Init_Fast2(); //Fast refresh initialization.
      EPD_WhiteScreen_ALL_Fast2(gImage_1); //To display one image using fast refresh.
      EPD_DeepSleep(); //Enter the sleep mode and please do not delete it, otherwise it will reduce the lifespan of the screen.
      delay(1000); //Delay for 1s.
      EPD_HW_Init_Fast2(); //EPD init Fast
      EPD_WhiteScreen_ALL_Fast2(gImage_2); //To display the second image using fast refresh.
      EPD_DeepSleep(); //Enter the sleep mode and please do not delete it, otherwise it will reduce the lifespan of the screen.
      delay(1000); //Delay for 1s.     
  #endif
  
   Serial.println("Start Plantpal Partial refresh demostration test!");
  #if 1 //Partial refresh demostration.
  //Partial refresh demo support displaying a clock at 5 locations with 00:00.  If you need to perform partial refresh more than 5 locations, please use the feature of using partial refresh at the full screen demo.
  //After 5 partial refreshes, implement a full screen refresh to clear the ghosting caused by partial refreshes.
  //////////////////////Partial refresh time demo/////////////////////////////////////
      EPD_HW_Init(); //Electronic paper initialization. 
      EPD_SetRAMValue_BaseMap(gImage_basemap); //Please do not delete the background color function, otherwise it will cause unstable display during partial refresh.
      for(i=0;i<6;i++)
      EPD_Dis_Part_Time(64,56+32*0,Num[i],         //x-A,y-A,DATA-A
                        64,56+32*1,Num[0],         //x-B,y-B,DATA-B
                        64,56+32*2,gImage_numdot, //x-C,y-C,DATA-C
                        64,56+32*3,Num[0],        //x-D,y-D,DATA-D
                        64,56+32*4,Num[1],32,64); //x-E,y-E,DATA-E,Resolution 32*64
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

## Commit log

2023-09-21 add ext crystal and rtc crystal
    [plantpal.kicad_sch]
2023-09-22 add esp32, usb, charger, power gate, and soil moisture
    [plantpal.kicad_sch]
2023-09-22 separate schematics
    [battery.kicad_sch, display.kicad_sch, main_controller.kicad_sch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]
2023-09-22 fix label
    [battery.kicad_sch, display.kicad_sch, main_controller.kicad_sch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]
2023-09-22 schematic restructure update
    [battery.kicad_sch, main_controller.kicad_sch, plantpal.kicad_sch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]
2023-09-23 beautify schematic
    [battery.kicad_sch, main_controller.kicad_sch, plantpal.kicad_sch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]
2023-09-23 first pass schematic and new fpc symbol
    [battery.kicad_sch, display.kicad_sch, main_controller.kicad_sch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]
2023-09-23 solar power schematic done
    [solar_power.kicad_sch]
2023-09-23 usb power schematic partially done
    [usb_power.kicad_sch]
2023-09-24 usb power schematic done
    [usb_power.kicad_sch]
2023-09-24 battery schematic done
    [battery.kicad_sch]
2023-09-24 power gate reg partially done
    [power_gate_and_regulator.kicad_sch]
2023-09-24 power gate reg done
    [power_gate_and_regulator.kicad_sch]
2023-09-24 partial work on main controller schematic
    [main_controller.kicad_sch]
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2023-09-24 update work on main controller
    [main_controller.kicad_sch]
2023-09-24 wip main controller schematic
    [main_controller.kicad_sch]
2023-09-24 main controller sch done
    [main_controller.kicad_sch]
2023-09-24 sensor sch partially done
    [sensor.kicad_sch]
2023-09-24 sensor sch done
    [sensor.kicad_sch]
2023-09-24 change resistor to 0402
    [battery.kicad_sch, display.kicad_sch, main_controller.kicad_sch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]
2023-09-24 update note
    [display.kicad_sch]
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2023-09-24 display sch done
    [display.kicad_sch]
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2023-09-24 update fottprint
    [display.kicad_sch]
2023-09-24 update button fp
    [main_controller.kicad_sch]
2023-09-24 update main controller
    [main_controller.kicad_sch]
2023-09-26 partially group components
    [plantpal.kicad_pcb]
2023-09-27 change rf antenna rf matching inductor to 0402
    [main_controller.kicad_sch]
2023-09-28 group components
    [plantpal.kicad_pcb]
2023-09-30 wip pcb
    [plantpal.kicad_pcb]
2023-09-30 move soil sensor pin and add it to main pcb
    [main_controller.kicad_sch, plantpal.kicad_pcb]
2023-10-01 add gnd for matching rf radio
    [main_controller.kicad_sch]
2023-10-01 change batt footprint
    [battery.kicad_sch]
2023-10-01 work in progress
    [plantpal.kicad_pcb]
2023-10-01 change usb polarity
    [usb_power.kicad_sch]
2023-10-03 update 3d model
    [plantpal.kicad_pcb]
2023-10-03 add testpad and wip
    [main_controller.kicad_sch, plantpal.kicad_pcb, usb_power.kicad_sch]
2023-10-03 add testpin for chip_enable
    [main_controller.kicad_sch, plantpal.kicad_pcb]
2023-10-04 wip wake-up button
    [main_controller.kicad_sch, plantpal.kicad_pcb, plantpal.kicad_sch]
2023-10-04 wip wake up button
    [main_controller.kicad_sch, plantpal.kicad_sch, power_gate_and_regulator.kicad_sch]
2023-10-05 update library
    [main_controller.kicad_sch, power_gate_and_regulator.kicad_sch]
2023-10-06 improve usb trace
    [plantpal.kicad_pcb]
2023-10-06 change charge rate to 1A
    [usb_power.kicad_sch]
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2023-10-06 add production file
    [TeapotlabsPlantpal_CPL.csv]
2023-10-07 change fpc connector
    [display.kicad_sch]
2023-10-07 update bom
    [power_gate_and_regulator.kicad_sch, usb_power.kicad_sch]
2023-10-07 add jst battery
    [battery.kicad_sch, plantpal.kicad_pcb]
2023-10-07 update production file
    [TeapotlabsPlantpal_BOM.csv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]
2023-10-07 remove via in pad
    [plantpal.kicad_pcb]
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2023-10-17 update docs to rev 2
    [battery.kicad_sch]
2023-10-24 update production for revision 2
    [TeapotlabsPlantpal_CPL.csv]
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2023-10-24 update incorrect D1 value
    [TeapotlabsPlantpal_BOM.csv, plantpal.kicad_pcb, usb_power.kicad_sch]
2024-01-04 fix D6 polarity
    [display.kicad_sch, plantpal.kicad_pcb]
2024-01-04 wip: removing powergate
    [main_controller.kicad_sch, plantpal.kicad_pcb, plantpal.kicad_sch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]
2024-01-04 wip: revision 2
    [main_controller.kicad_sch, plantpal.kicad_pcb, plantpal.kicad_sch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]
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2024-01-07 re-route sense out, add display power switch
    [display.kicad_sch, main_controller.kicad_sch, plantpal.kicad_sch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]
2024-01-11 revision 3 prod
    [TeapotlabsPlantpal_BOM.csv, main_controller.kicad_sch, plantpal.kicad_pcb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]
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2024-01-12 add additiontal documents
    [bill_of_materials.csv]
2024-01-17 fix schematic info
    [battery.kicad_sch, display.kicad_sch, main_controller.kicad_sch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]
2024-02-02 re-wire epd power
    [battery.kicad_sch, display.kicad_sch, main_controller.kicad_sch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]
2024-02-02 clean-up rewire
    [plantpal.kicad_pcb]
2024-02-02 rewire epd power
    [plantpal.kicad_pcb]
2024-02-03 update revision silkscreen to 4
    [plantpal.kicad_pcb]
2024-02-03 add pin 1 indicator for inductor
    [plantpal.kicad_pcb]
2024-02-03 add case
    [bottom.stl, display_support.stl, top.stl]
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2024-04-06 update to kicad 8
    [battery.kicad_sch, display.kicad_sch, main_controller.kicad_sch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]
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2024-04-15 change antenna trace width to latest pcb stack-up
    [plantpal.kicad_pcb]
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2024-07-09 update docs with resin images
    [bottom.stl, display_support.stl, top.stl]

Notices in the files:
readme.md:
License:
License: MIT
